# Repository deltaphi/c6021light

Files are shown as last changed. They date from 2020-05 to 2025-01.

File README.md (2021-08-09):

connect6021 light für Keyboard 6040
===================================



Project to connect one or several Keyboard 6040s to CAN. This project replaces the 6021 in your system.

To find out more about how to use the c6021light, take a look at the [User Manual](c6021light/doc/c6021light_UserManual.md).

## Safety Notes

When a button on the Keyboard is released, the Keyboard generates a "Power Off" command.
Unfortunately, the command does not directly translate to CAN. On CAN, commands are always sent
to the address of a specific accessory. The Keyboard 6040 however addresses 8 accessories at once.
There is a heuristic in the software to guess the address of the accessory to turn off. However,
this heuristic can be tricked and a power off command may not be sent to the correct address.

Please make sure to independently limit the Power On time of all accessories.

## Notes on Supply Power

The Keyboard operates on 8V. Note that its power draw is quite significant at about 120mA for a
single device.

The I2C bus operates at 5V.

# I2C Bus

## Hardware

Belegung der Buchse (Keyboard 6040 links)
```
SDA  SCL  STOP GO        INIT 8V   8V
 2b   4b   6b   8b  10b  12b  14b  16b
 2a   4a   6a   8a  10a  12a  14a  16a
GND  GND  GND  GND  GND  GND  GND  GND
```

Federleiste DIN 41612 32-pol B/2
z.B. ept 102-90065

http://dl1zax.selfhost.de/ATMega/PDF/6022.pdf

## I2C Bus Communication

Zitat von [Dr. König's Märklin-Digital-Page](http://www.drkoenig.de/digital/i2c.htm) (Text von Walter Fiedler):
```
Für die Übertragung von Weichenstellbefehlen genügen drei Byte als Schaltanforderung.
Es sind dies die Bytes für Empfänger (Zentrale), Keyboard-Nr. (0 bis 15) und das Datenbyte.
Das Datenbyte enthält die Angabe der Decoder-Ausgangsnummer (Bits 0 bis 3) und der Decoder- Teiladresse (Bits 4 und 5).
Mit Bit 0 wird die Schaltrichtung bestimmt (0=Rot, 1=Grün), mit Bit 3 wird der Schaltstrom eingeschaltet.
Da mit einem Keyboard (6040) vier Decoder angesprochen werden können, bestimmen die Bits 4 und 5, um welche Vierergruppe von Tastenpaaren und somit für welchen der vier für dieses Keyboard zuständigen Decoder sich der Schaltbefehl handelt.
Bei der Bildung der realen Decoder-Adresse (im binären Zahlenformat) stellen diese zwei Bits die Bits 0 und 1 dar. Die vier Bits der Keyboard-Adresse bilden dann die Bits 2 bis 5 der Decoder-Adresse. Diese Decoder-Adresse wird noch um 1 erhöht, da die Decoder-Adressierung im Märklin Digital-System immer mit der Adresse "01" beginnt. Somit können maximal 64 Decoder im Bereich von "01" bis "64" angesprochen werden.
Aufbau des Datenbytes:

    Bit 0 = Schaltrichtung, 0=Rot, 1=Grün
    Bit 1 = Decoderausgang LSB (Least Significant Bit)
    Bit 2 = Decoderausgang MSB (Most Significant Bit)
    Bit 3 = Schaltstrom, 0=aus, 1=ein
    Bit 4 = Decoder-Teiladresse LSB
    Bit 5 = Decoder-Teiladresse MSB 

Aufbau der Schaltanforderung:

Empfänger		Sender			Datenbyte		Stoppbits
1111 1110	0	001X XXX0	0	00XX XXXX	0	10
Zentrale	Q	Geräte-Adr.	Q			Q

Die Bestätigung von der Zentrale lautet:

Empfänger		Sender			Datenbyte		Stoppbit
001X XXX0	0	1111 1110	0	00XX XXXX	0	0
Geräte-Adr.	Q	Zentrale	Q			Q

```

Sequenz

Taste 0 rot

0xfe 0x20 0x08

0x20 0xfe 0x08 (Osci wA 0x10 -> Data 0x20)

### I2C Messages

Devices communicate over I2C. The system is multi-master, i.e., any device that has data to send
as as a master. Read from slave devices is not used.

The message format for Keyboards (Accessory commands) is as follows:

receiver sender data

* receiver is the I2C slave address the message is sent to. Thisi s not sent as a separate data
  byte but as the address byte of the I2C communication.
* sender is the I2C slave address under which the originator of the message can be reached.
* data The data byte, containing the action to be performed.

#### I2C Device Addresses

Note that I2C addresses are 7 Bit. However, the above mentioned fields are all 8 bit. In practice,
this results in the fact that the receiver address and sender address are shifted by 1 bit. In the
following, all addresses are given as their I2C slave address repesentation (i.e., the value
observed in the receiver field).

* The Central Unit uses the slave address 0x7F.
* Keyboard 0 uses a slave address of 0x10. The Keyboard address is derived from the DIP switches on
  the back.

#### I2C Data Byte

The data byte is constructed as follows:

`[0 0 Decoder_MSB Decoder_LSB Power Output_MSB Output_LSB Direction]`

Addressing on decoders on I2C is centered around the original approach, where a decoder had one
decoder address (set with DIP switches) and eight outputs. The KEyboard Address together with
the Decoder_* bits identify a decoder. The Output_* bits together with the Direction bit identify
one output of the decoder.

Modern Systems use individually addressable decoders (Keyboard Address + Decoder_* + Output_*) and
treat the direction separately.

### Keyboard Message flow

The Keyboard does not need any initialization. As soon as 8V are applied to one of the power pins
and the I2C lines are pulled up to 5V (a 10k resistor on each line does the job) it starts up and
the turnout indicators set at the last shutdown light up.
 
When a button is pressed, a message is sent to the Central Unit. When no Device with the address
of the Central Unit is present on the bus, the `receiver` byte will not be Acknowledged. In this
case, the Keyboard will abort transmission of the remaining bytes. It will then try resend the
message immediately and indefinitely, possibly blocking the bus.

If the message is received (i.e., a device with the address of the Central Unit is present on the
bus and ACKs the bytes), the Keyboard expects a response. If the response is not received, it
resends its original request indefinitely about once per second.

If no response is received, the indicators on the Keyboard don't change. Also, pressing additional
buttons has no effect. The Keyboard is stuck processing the original request. If a response is
received even when no corresponding request was sent, the indicators always change and no further
processing takes place on the Keyboard.

#### Power On/Off

When a button is pressed, a "Power ON" message is sent. When a button is released, a "Power OFF"
message is sent. However, due to the Decoder-Based addressing scheme, the "Power Off" message is
not addressed towards a specific turnout but towards the decoder Address, i.e., all 8 outputs are
considered to be unpowered.

# LocoNet

## Hardware

Looking from the top, the lines on the LocoNet connector are as follows:

```
 6      5    4    3     2   1
PWR    GND DATA  DATA  GND PWR
+8V    0V  +14V  +14V  0V  +8V    (Measured from IB1)
+9V    0V  +8,7V +8,7V 0V  +9V    (Measured with J31/J32 closed, 10V supply voltage)
+11,4V 0V  +10V  +10V  0V  +11,4V (Measured with J31/J32 closed, 12V supply voltage)
```

## Message Sequence for Dispatch

Recorded from IB1.

Request dispatch form FREDI, no Slot in dispatch:
```
LN RX:  ba 0 0 45 [OPC_MOVE_SLOTS] 0 -> 0
LN RX:  b4 3a 0 71 [OPC_LONG_ACK]
```

Dispatch engine 50 on IB1:
```
LN RX:  b5 1 10 5b [OPC_SLOT_STAT1] Slot: 1 Stat1: 0x10
LN RX:  bf 0 32 72 [OPC_LOCO_ADR] Addr 50
LN RX:  e7 e 1 10 32 0 0 7 0 0 0 10 4 26 [OPC_SL_RD_DATA] Slot: 1 Stat: 16 Addr: 50 Speed: 0 Dirf: 00 ...
LN RX:  ba 1 0 44 [OPC_MOVE_SLOTS] 1 -> 0
LN RX:  e7 e 1 20 32 0 0 7 0 0 0 10 4 16 [OPC_SL_RD_DATA] Slot: 1 Stat: 32 Addr: 50 Speed: 0 Dirf: 00 ...
```

Request dispatch from FREDI, Engine 50 in dispatch:
```
LN RX:  ba 0 0 45 [OPC_MOVE_SLOTS] 0 -> 0
LN RX:  e7 e 1 30 32 0 0 7 0 0 0 10 4 6 [OPC_SL_RD_DATA] Slot: 1 Stat: 48 Addr: 50 Speed: 0 Dirf: 00 ...
LN RX:  ef e 1 30 32 0 0 7 0 0 0 10 4 e [OPC_WR_SL_DATA] Slot: 1 Stat: 48 Addr: 50 Speed: 0 Dirf: 00 ...
LN RX:  b4 6f 7f 5b [OPC_LONG_ACK]
```

# Overall Communication Pattern

connect 6021 light connects the following bus systems:

* CAN
* I2C
* LocoNet
* XPressNet

In the future:
* MM2-Sniffer
* IR Receiver
* Serial Commands

There should be a central routing task that iterates over all ingress ports and if data is available, forwards the data over the respective egress ports.

Ingress and Egress may be polling-based (e.g., CAN) or interrupt-based (e.g., I2C, LocoNet). Also, input may be driven by concurrent tasks (Serial?).
Polling-based operation complicates scheduling, as the routing task can never go to sleep. It would be helpful if 

As for Datastructures: Is there an ingress queue/egress queue per bus, or is there a central queue that also notes down the ingress bus?

Overall Tasks:
* RoutingTask (needs: RR32Can, DataModel, HAL for CAN, HAL for I2C)
* Console Task

ISRs:

* I2C ISR (Send/Receive, Ingress/Egress Buffer. Egress can not be an OS queue.)
* LocoNet ISR (Send/Receive)

## Task/ISR Design

I2C ISR:
* TX Buffer, RX Buffer
* Bytes are read into RX Buffer. When buffer is full, place message into message queue (Copy!). Notify routing task when Message is complete (copy!). -> Note: As long as the RX part does not overrun, the Queue is not necessary. Code change may involve changing the synchronization primitives.
* Routing Task places TX message into queue (copy!). When TX Buffer is free, it copies (copy!) a message from the queue to the TX Buffer and starts the ISR. -> Note: As long as the TX part does not overrun, the Queue is not necessary. Code change is only adding the queue operation into the routing task.

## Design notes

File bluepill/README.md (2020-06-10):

STM32 C6021Light
================

Universal Maerklin CAN to Maerklin I2C / RS485 / Loconet Board

3D Board

Based on Blue Pill

STM32F103C8T6 microcontroller development board

using libopencm3 (real OpenSource - no questionable STMicroelectronics License)

CAN-Interface
-------------
```
/* CAN1 / CAN GPIO */
#define GPIO_CAN_PB_RX                  GPIO8           /* PB8 */
#define GPIO_CAN_PB_TX                  GPIO9           /* PB9 */
/* I2C2 / I2C GPIO */
#define GPIO_I2C2_SCL1                  GPIO6           /* PB6 */
#define GPIO_I2C2_SDA1                  GPIO7           /* PB7 */
```

Flashing Serial
---------------
using SWD interface with st-flash or serial loader stm32-flash (works only with USART1)

```
/* USART1 GPIO */
#define GPIO_USART1_TX                  GPIO9           /* PA9 */
#define GPIO_USART1_RX                  GPIO10          /* PA10 */
```

Compile under Ubuntu/Raspbian
-----------------------------
```
sudo apt-get install git gcc-arm-none-eabi stm32flash

sudo mkdir -p /embedded/arm-cortex/src
sudo chown -R "$(whoami).$(whoami)" /embedded

cd /embedded/arm-cortex/src
git clone https://github.com/libopencm3/libopencm3.git
cd libopencm3
make PREFIX=arm-none-eabi-

cd ~
git clone https://github.com/GBert/railroad
cd railroad/c6021light/bluepill
make # make stm32flash
```

Links
-----

more information here: https://wiki.kewl.org/dokuwiki/boards:vcc-gnd

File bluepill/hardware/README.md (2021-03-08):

Aenderungen
===========

```
1.0 Initiale Version

1.1 2020/06
    CAN RJ45 Pin 5 getrennt um CdB konform zu bleiben
    Buchse verschoben damit die gewinkelte Version besser passt
    DCDC Enable 12V getrennt
    Mehr Platz fuer DCDC Wandler
    USB/Seriell Wandler: 0 Ohm Widerstaende entfernt
    UART Leiste angepasst

1.2 2020/12
    Loconet C32 entfernt

1.3 2021/01
    TxD und RxD getauscht auf J52 Pin Header für Standard USB2Serial Module

1.4 2021/03
    mehr Platz für Spannungsregler
    C30 wahlweise 2,5 oder 5 mm Rastermaß
    
```

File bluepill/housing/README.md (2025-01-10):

The Housing was created using [OnShape](https://www.onshape.com/).
Find the original document at [c6021light Housing](https://cad.onshape.com/documents/e49e89ad6c23c5cdc841251d/w/302afb60d0e915079a89c67e/e/e77f569449b81789304b1466).

This folder currently contains an export of the Tag "V3".

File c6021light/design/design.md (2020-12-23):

# C6021 Light Software Design

The c6021light software consists of several building blocks and several OS tasks.

```plantuml
@startuml Software Overview

component RoutingTask

component ConsoleTask
component ConsoleManager

component DataModel

package "hal" {

component stm32usart
component stm32i2c
component stm32can
component stm32eepromEmulation

component libopencm3
}

package "Libraries" {
    component RR32CanLibrary
    component LocoNet
    component AtomicRingBuffer

    component FreeRTOS
    component microrl
    component nimaltd_ee
}

@enduml
```

## Tasks and Interrupts

The following FreeRTOS tasks exist in the system:

* RoutingTask
* ConsoleTask

ConsoleTask is a low-priority task, as it never blocks. RoutingTask is the highest-priority task in the system and is run only when there is data to be forwarded.

The following component make use of interrupts:

* stm32usart (DMA1 Channel4 Transmission Finished)
* stm32i2c (Transmission complete, I2C Error Handling)
* stm32can (CAN Message Received)
* LocoNet (TIM2 Timer Compare interrupt)

## Serial Command Line Interface and Output

c6021light makes use of the command line to print information data such as received and transmitted packages as well as to offer a command line interface to configure settings, such as the rail protocol to be used for turnout requests.

Implementation of this interface is spread over the following components:

* ConsoleTask
* ConsoleManager
* microrl
* stm32usart
* AtomicRingBuffer

stm32usart implements the serial communication to a remote device, e.g., a PC using a USB-to-Serial adapter. For the output path (c6021light to PC) stm32usart implements the `_write()` syscall. `_write()` copies the provided string data to a circular buffer (thereby using AtomicRingBuffer) and starts a DMA transfer to output the buffered data on the serial interface.

If the provided data fits into the buffer, the call returns after copying the data and starting the DMA. If the provided data does not fit into the buffer, `_write()` will busy-wait until all of the data could be forwarded into the buffer.

When the DMA transfer completes and there is data left in the buffer (e.g., because more data was added while a DMA transfer was ongoing), the DMA transfer is restarted with the new data.

For the input path (PC to c6021light), stm32usart provides the call `pollSerial()`. This call will return whether a character was read and if so, also return the appropriate character. `pollSerial()` is called by the ConsoleTask in an infinite loop, thereby polling for serial input. If data is read, ConsoleTask inputs the read data into microrl.

microrl provides command line parsing, command line history and command line completion. When a user enters a valid command, the command is mapped to a C function which is subsequently executed. ConsoleManager holds the configuration for microrl as well as the implementation of the applications.

## Runtime Configuration Data

c6021light allows runtime configurable settings to be done via the command line interface. The settings data is stored in the topmost program flash page. The following components interact with the configuration data:

* ConsoleManager
* DataModel
* stm32eepromEmulation
* FlashFairyPP

DataModel holds the actual runtime configuration data. All components wishing to read or write configuration data must do so by accessing a central instance of DataModel. ConsoleManager can be used to trigger a write of the current DataModel to persistent flash storage from the command line interface. Flash handling is performed by FlashFairyPP, where stm32eepromEmulation adds a few callbacks to map FlashFairyPP to libopencm3.

## Bus communciation routing

For every bus, there is a bus-specific communication implementation: stm32can, stm32i2c, LocoNet.

### stm32can

The stm32can part contains setup and reception/transmission of CAN messages. Messages are received through the CAN0 RX ISR. Whenever the interrupt is executed, all messages pending in the buffer are copied to a FreeRTOS queue and a task notification is sent to the RoutingTask.

```plantuml
@startuml stm32can message reception

CANCell -> stm32can: CAN RX ISR
stm32can -> canrxq: Copy message from HW FIFO to OS Queue
stm32can -> RoutingTask: Notify
canrxq --> RoutingTask: Get Message for Routing

@enduml
```

For transmission, messages are synchronously sent to the transmit mailbox of the CAN cell.

```plantuml
@startuml stm32can message transmission

RoutingTask -> stm32can: Send Message
stm32can -> CANCell: can_transmit()

@enduml
```

All interaction is based on RR32Can data types.

### LocoNet

The LocoNet library uses a level change interrupt and a timer compare interrupt to simulate a UART interface in software. It makes use of Hardware Timer TIM2.

To receive a LocoNet packet, the SW UART implementation of LocoNet recieves individual bytes which are then stored in a circular buffer. ConsoleTask is currently abused to poll wheter LocoNet has received new bytes and if so, to wakte the RoutingTask. However, ConsoleTask will wake RoutingTask even if only a partial message was received. To determine whether a complete message was received, RoutingTask asks the LocoNet library for the next message. The LocoNet library will provide a message only when a complete message is available in the buffer.

Note that in case a message wraps around in the buffer, the LocoNet library will briefly suspend interrupts to copy the message to a contiguous location in the circular buffer.

To send a LocoNet message, LocoNet sets up a message for transmission and then busy-waits until the timer interrupt has finished sending all bytes of the message. busy-waiting is necessary as the dat ais read from the caller-provided pointer, it is not copied to an internal buffer.

### I2C

When idle, the I2C hardware is configured as an I2C slave with address 0x7F. Other devices may send messages to this ID. Message bytes are received by the I2C1 ISR. A message is considered to be completely received when an I2C Stop Condition occurs or when an I2C Bus Error interrupt occurs. The latter enables successful interaction with certain non-conforming devices. When a message is successefully received, it is enqueued in the i2crx FreeRTOS queue and the RoutingTask is woken.

To send a mesasge via I2C, a caller needs to put the message into the i2ctx queue and then call `startTx()`. If a transmission or reception is already ongoing, `startTx()` will do nothing. The next transmission or reception is started automatically once the current action completes. If no interaction is currently ongoing, `startTx()` causes the Hardware to send an I2C Start Condition which triggers subsequent calls to the I2C ISR, which then, in turn, transmits the individual bytes of the message.

When the I2C bus is empty, apart from c6021light, every attempt at transmission will be met with an Acknowledgement Failure (AF). In case of an AF, the current message is discarded. The I2C interface is not sent into an error state but following messages are transmitted in the same way. If the bus remains empty, every message will be discarded with an acknowledgement failure. If a device "suddenly" appears on the bus that receives the message, communication will resume.

## RoutingTask

The operating principle of the routing task is that messages received from every bus are first converted into their representation as it would be on the CAN bus. Next, a routing decision is taken. Currently, the routing decision is to forward a message to every bus apart from the bus that it was received from. Finally, for every bus, the CAN representation is converted to the respective bus representation and a message is sent on the respective bus.

Note that for most busses, the respective library used offers capabilities to decode and handle or to send bus messages. However, for many cases these implementations are not used, as the resulting software design leads to a jumble of hard-to-follow callbacks and repeated implementation of routing decisions and forwardings. However, to enable operations other than forwarding, the c6021light considers itself to be a RR32Can::Station instance that is not directly connected to any bus. Instead, the RoutingTask forwards every received message to the RR32Can::Station for processing.

Currently, the only processing that occurs is to turn on the LED on PC13 if any bus signals a stop mode and to turn off the LED if any bus signals a start mode.

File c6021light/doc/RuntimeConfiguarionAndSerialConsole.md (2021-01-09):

# Runtime Configuration

Various settings of the c6021light can be adjusted at runtime using the serial interface. To connect to the serial interface of the c6021light, follow the instructions on the project Wiki for [Connecting to the serial console](https://github.com/deltaphi/c6021light/wiki/ConnectToSerialConsole). Make sure that you can see the command prompt `c6021light > ` before continuing.

## Interacting with the Serial Console

The c6021light has a built-in help that tells you about possible options available in your version of the software. To display the help, simply type `help` into the serial console and press Enter. On the current version of the software, the help looks as follows:

```
c6021light > help
Available commands:
  config ... - Change runtime configuration.
  flash ... - Operations on persistent storage.
  lnSlotServer ... - Control the LocoNet Refresh Slot server.
  canEngineDB ... - Control the Can Engine DB.
  help - Display this help message.
c6021light >
```

Each line consists of several elements. The first element is always a *command*, e.g., `config`. The command tells the c6021light what you want to do. The second element are three dots `...`. These dots indicate that a command cannot be executed on its own but has further subcommands. Note that the dots are optional. For example, `help` does not have subcommands. If there is a help text configured for a command, the dots are followed by a dash (`-`) and the actual help text.

To find out more about available subcommands, simply type the name of the command and press Enter. If the command is incomplete, you will automatically get another help text for the next level of subcommands. Consider the following example:

```
c6021light > config get
Available commands:
  config get ... - Display configuration value.
  config set ... - Modify configuraiton value. 
c6021light >
```

You can use this to explore the tree of commands offered by the c6021light. Let's take the example a bit further and look at `config set turnoutProtocol`:

```
Available commands:
  config set turnoutProtocol MM2
  config set turnoutProtocol DCC
  config set turnoutProtocol SX1
```

Neither of these commands have dots. That means that these are complete commands. If you were to type them in, they will immediately be executed.

Note that when you use the serial console to change a configuration value, the change takes effect immediately. However, the change will be forgotten by the next reset (e.g., power cycle of your layout) unless you [persist the configuration](#persistent-storage-of-configuration-options).

# Serial Configuration Options

This is an incomplete description of runtime configuation options. Refer to the command line help of your c6021light to find out what options your firmware version of the c6021light offers.

| Setting | Possible Values | Default Value | Description |
|---|---|---|---|
| `turnoutProtocol` | `MM2`, `DCC`, `SX1` | `MM2` | Protocol to address turnouts on the Rail. Only affects forwarding of messages on CAN. |
| `lnSlotServer` | `disabled`, `passive`, `active` | `disabled` | Forwarding of Locomotive control commands between CAN and LocoNet. Disabled completely disables forwarding of Locomotive control messages. Passive requires a LocoNet Central on LocoNet. Active (not implemented) simulates a LocoNet Central for other control terminals on LocoNet. |

# Convenience Features of the Serial Console

The serial console of the c6021light offers two convenience features: Tab-completion and command history.

## Tab Completion

When you enter a prefix command of a command known to the c6021light, press the `Tab` key to trigger the tab completion. If the prefix you entered matches exactly one command, the c6021light will auto-complete the remainder of the current command word for you. For example: ```c6021light > h<Tab>``` will complete to ```c6021light > help```. In contrast, ```c6021light > c<Tab>``` will not auto-complete, as the 'c' could match either `config` or `canEngineDB`. If you extend the command line to ```c6021light > co<Tab>```, the command will complete to ```c6021light > config```.

## Command History

If you want to execute a previous command again or want to edit a previous command, you can use arrow up and arrow down to navigate through the command history.

Note that this feature does not work with all serial terminal applicaitons. Specifically, it is known not to work with the PlatformIO IDE serial terminal.

# Persistent storage of configuration options

When you change a value using the serial console, the change takes effect immediately but is not persistet across resets of the c6021light such as caused by a power cycle. To store configuration data across resets of the boards, the c6021light utilizes the internal flash of the STM32 controller on the bluepill board.

The serial interface offers several commands to interact with the flash memory. Use `flash save` to save the current configuration persistently. The configuration will automatically be loaded every time the board is reset.

To revert the c6021light to the default settigns of the software version currently installed, use the command `flash format`. It is not usually necessary to use this command.

If you feel really curious, `flash dump` gives you a raw view into the contents of the flash pages used to store configuration data. This command is used during software development.

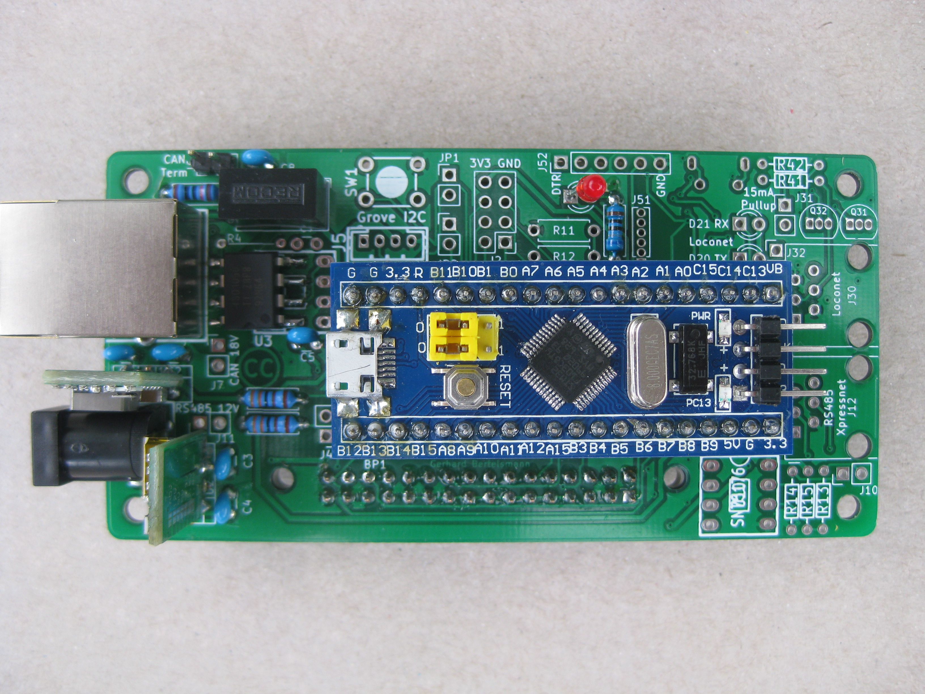
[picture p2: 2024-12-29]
pictures/board_02.jpg

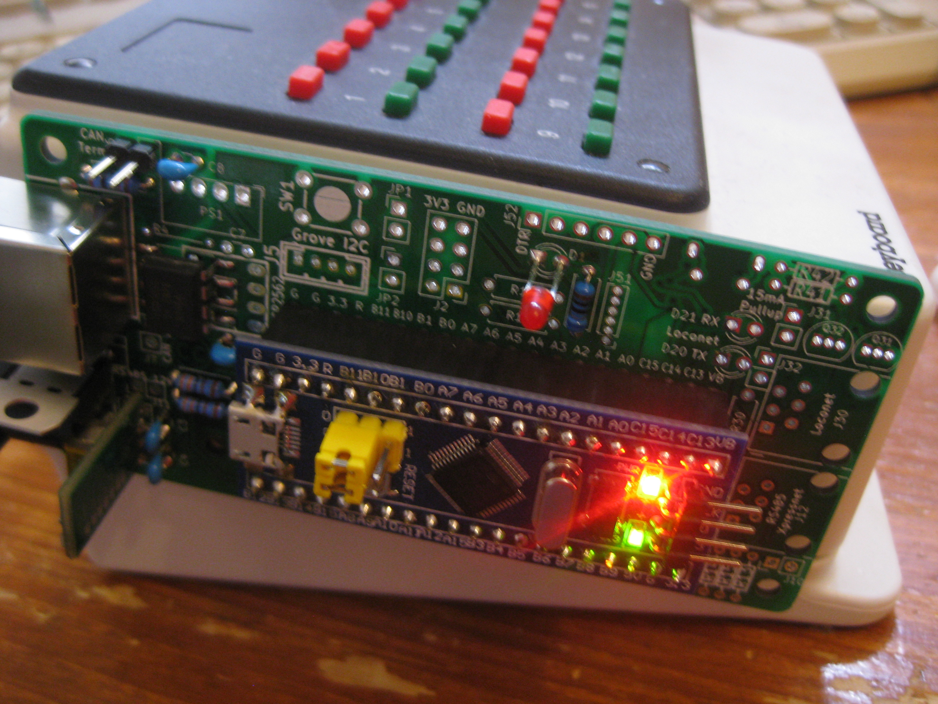
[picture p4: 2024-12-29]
pictures/board_kb_01.jpg

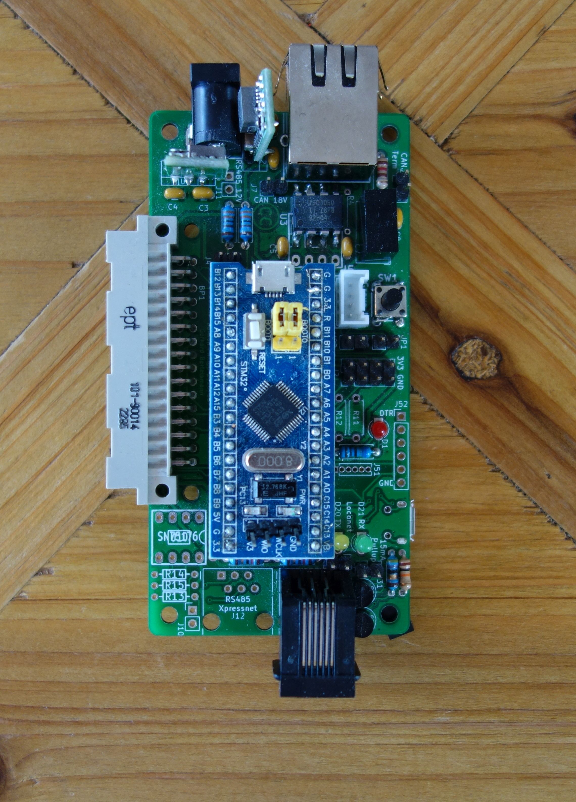
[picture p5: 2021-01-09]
c6021light/doc/images/c6021light_pcb_v1_0.jpg

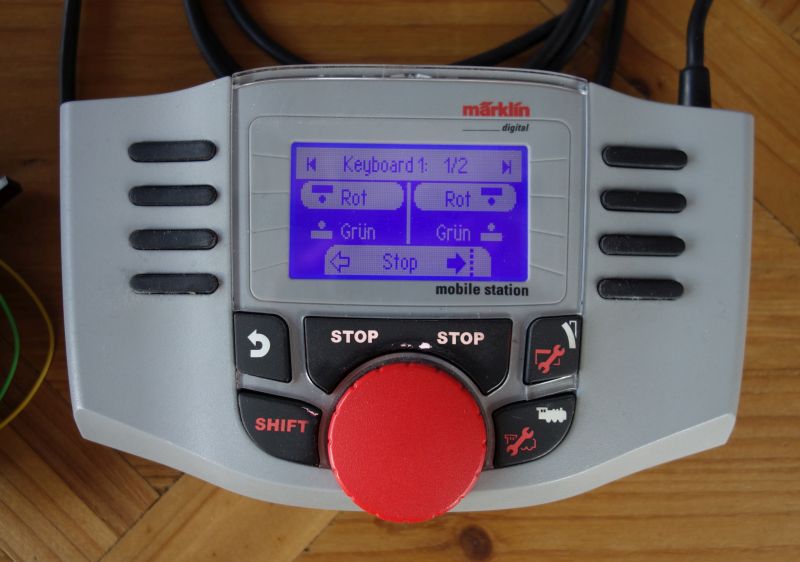
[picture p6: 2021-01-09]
c6021light/doc/images/ms2_turnout_stop.jpg

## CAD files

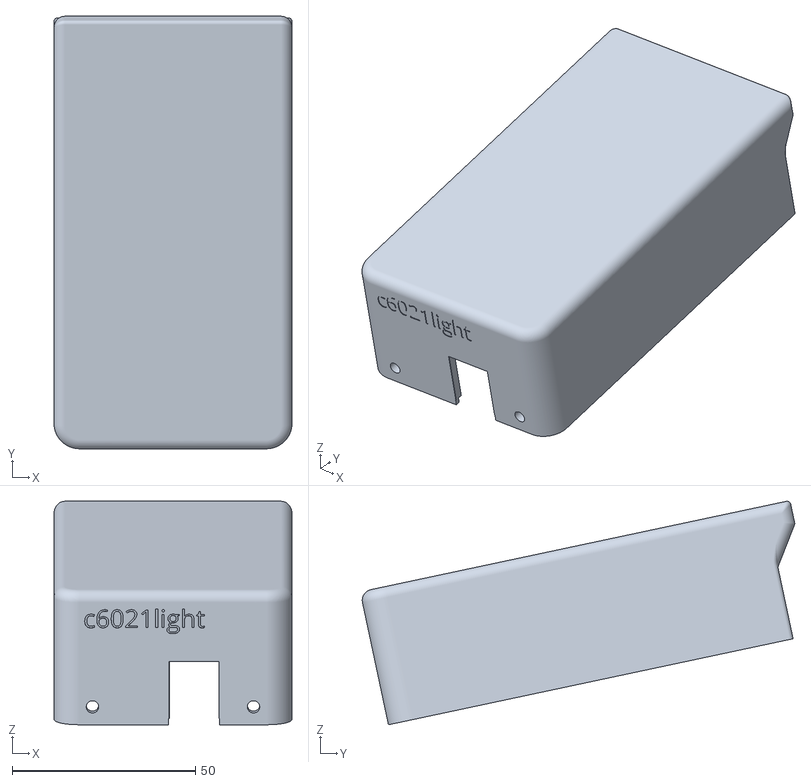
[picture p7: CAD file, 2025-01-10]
bluepill/housing/c6021lightHousing - Top.stl
65.0 x 118.1 x 61.1

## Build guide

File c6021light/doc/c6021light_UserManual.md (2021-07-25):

# c6021light User Manual

c6021light is a project that connects devices on the following Model Railroad control networks:

* Marklin devices on CAN bus
* Marklin devices on I2C bus
* LocoNet devices

In the current version, c6021light transfers turnout commands between all three busses.
It also transfers sensor commands (e.g., from an S88 Bus or LocoNet track sensor), synchronizes the Stop/Go state (Track Power On/Off) and translated Locomotive control commands between Marklin System CAN and LocoNet.

Unfortunately, transfering locomotive control commands is not as straight-forward as transfering other commands. c6021light employs heuristics in an attempt to provide a seamless railroading experience. Nevertheless, it is in the nature of these heuristics that they may fail and that you may have to manually configure c6021light to correctly transfer locomotive control commands. See the [General Operation](GeneralOperation.md) section for more details.

*Please be aware of the following safety note: When controlling accessories such as turnouts from the Marklin Digital devices on an I2C bus, there is no reliable way to translate a "Turnout Power Off" event to other bus systems. c6021light employs a heuristic to guess which accessory output should be powered off. However, a power off command still may not be sent to the correct accessory, possibly causing permanent damage to your model railroad, e.g., by burning out a turnout actuator coil, possibly even setting the accessory on fire. Make sure to use additional, independent protective measures to limit the on-time of sensitive devices attached as an accessory to avoid any potential for damage.*

## Table of Contents

The user manual for the c6021light is split into several chapters.

**As a new user, you should begin setting up your c6021light with the [Getting Started Guide](GettingStarted.md).**

* [Getting Started Guide](GettingStarted.md) - This is the entry point for all new users. Even if you already have your c6021light running, it is recommended to at least skim this chapter as it will also introduce you to some gneral concepts of the c6021light.
* [General Operation](GeneralOperation.md) - Details the features of the c6021light as well as its operation principles.
* [Runtime Configuration & use of the Serial Console](RuntimeConfiguarionAndSerialConsole.md) - Details how to access the serial console and how to edit and persist the configuration.

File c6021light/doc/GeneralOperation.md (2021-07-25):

# General Operation

## LED Status Indicators

The c6021light features two status indicator LEDs: The "On-board LED" and the "Extra LED".

### On-board LED

The On-board LED can convey two types of information: Whether the system is in a regular operation state (LED on), whether a [CAN Engine Database Download](#can-engine-database) is ongoing (LED blinks slowly), or whether the system is in an error state (LED blinks fast).
There is also a mode where the LED is off, which is currently unused.

### Extra LED

Functionality of the "Extra LED" is described in the section on [System Power Status Indication](#system-power-status-indication).

## Turnout Control

Turnout contol messages are automatically forwarded between all bus systems. 

Turnout control messages on CAN carry information about the rail protocol used to contact the turnout decoder, whereas messages on I2C and LocoNet do not carry this information. Therefore, the configuration value `turnoutProtocol` is used to add protocol information to turnout control messages when forwarding to CAN. Similarly, the protocol information is stripped from messages when forwarding from CAN to other bus systems.

Devices on the I2C bus send out turnout control request messages and expect turnout control response messages in return, before they update their state indication (Keyboard) or proceed with processing (Memory). In the current version of the software, turnout control response message are generated only by a central device on the CAN bus that is not in the "STOP" mode. Devices on LocoNet do not generate turnout control response messages.

## Sensor Messages

Sensor messages are forwarded as-is between CAN and LocoNet in both directions. No configuration is required or possible.

## System Power Status (Stop/Go)

Stop and Go messages are forwarded as-is between CAN and LocoNet in both directions. No configuration is required or possible.

In addition, c6021light provides an indication of the last observed system state using the "Extra LED".

### System Power Status Indication

The "Extra LED" indicates whether the c6021light considers the system to be in a "Stop" state (LED off) or a "Go" state (LED on). In addition, the c6021light will flash the "Extra LED" when it has no information about the current Stop/Go state of the system.

The c6021light considers Stop/Go commands from all bus systems equally. Whenever a STOP- or GO-Command is received, it updates its internal state accordingly and sets the state of the LED. Not that the Stop/Go state of the system may be out of sync if any component of the system is reset or disconnected.

### System Power Status Download

After power on or reset, the c6021light has no information about the Stop/Go-State of the system and will start to flash the Extra LED. In parallel, it will send request messages to determine the Stop/Go state on the CAN bus. Unfortunately, not all CAN-based railroad control systems respond to this message. In this case, the c6021light cannot determine the Stop/Go state of the system until the first STOP or GO command is observed on any bus.

Lack of the current system state does not influence the forwarding of STOP/GO commands between bus systems.

## Locomotive Control

*Note that Locomotive Control is an experimental feature that is currently under development. It is not fully available between all bus systems and in all directions. Even if it is available, it may spuriously fail.*

### Overview over Locomotive Control

In contrast to all other types of information forwarded by c6021light, Locomotive Control is a more complex task. Turnout control, track sensors and Stop/Go messages work similarly on all bus systems. Therefore, messages can be forwarded by simply translating message formats between the bus systems. 

Locomotive Control, however, useses widely different message types and even message interactions and addressing schemes across the different bus networks. c6021light is capable of translating the message interactions for Locomotive Control between LocoNet and Marklin CAN, provided that it has state information about the engine control happening on both bus systems.

On LocoNet, Locomotives are assigned a control slot by the LocoNet Master. The Slot is associated with a Locomotive Address (e.g., the DCC decoder address sent on the track), but all control messages contain only the slot number.

On CAN, Locomotives are assigned a unique ID (UID). The UID is associated with the Locomotive Address and the track protocol for the Locomotive Address, but all control messages contain only the UID.

To successfully forward Locomotive Control Commands between CAN and LocoNet, c6021light therefore must know the CAN Engine Database as well as the LocoNet Slot Database.

Note that CAN considers both the Locomotive Address as well as the track protocol used for the respective address, whereas LocoNet uses only the Locomotive Address. It is (at least in theory) possible to control several Locomotives that use the same address on different Protocols (e.g., one Locomotive using MM2-50 and another using DCC-50) from CAN. LocoNet would not be able to distinguish control commands for these engines. It is therefore recommended that you give unique Locomotive Addresses to all of your Locomotives, independent of the rail protocol they use.

### Locomotive Control using c6021light

Forwarding of Locomotive control message is only enabled, when the configuration setting `lnSlotServer` is not set to `disabled`.
Furthermore, a CAN Engine DB must be available for the c6021light to be able to forward incoming Locomotive Control Messages.

#### LocoNet Slot Server

The LocoNet Slot Server offers two operating modes: `passive` mode and `active` mode.

In `passive` mode, the c6021light expects a LocoNet Master to be present on the bus, e.g., an Uhlenbrock IntelliBox. The LocoNet Master controls the assignment of Engines to Slots. In `passive` mode, the c6021light monitors the LocoNet bus for ongoing slot assignments and Locomotive Control Commands and caches all received information in its internal Slot Server.

In `active` mode, the c6021light acts as a LocoNet Master itself. Thus, it controls the assignment of Locomotives to slots both as other devices on LocoNet request Locomotive control slots and as control messages from CAN are forwarded for Locomotives currently not assigned a slot.

In the current implementation, engine speed, direction and Functions F0-F31 are forwarded from LocoNet to CAN. If no additional measures are taken, c6021light produces messages to an engine using the address entered on the control device on LocoNet, using the MM2 protocol.

#### CAN Engine Database

The c6021light can also obtain the list of known engines from a central device on the CAN bus using the command `canEngineDB downloadEngines`.
An ongoing download is indicated by flashing the "On-board LED".

Note that the download time is proportional to the number of engines in your database.
It will typically take several seconds to complete.
You can at any time view the list of engines known to the c6021light using the command `canEngineDB dump` on the serial command line.

To avoid having to manually download the CAN Engine Database every time the c6021light is reset or powered down, the c6021light will try to download the CAN Engine Database after power-up. Over the first ten seconds of its operation, it will request a download of the CAN Engine Database once every second.

#### Forwarding between CAN and LocoNet

If an Engine Database is available on the c6021light, it will try to find an engine with an address that matches the address entered on the LocoNet-side. If a match is found, the c6021light will forward messages for that engine.

In the reverse direction, i.e., CAN to LocoNet, no information is transmitted unless an engine database is available. If an engine database is available, the c6021light will attempt to control engines on the LocoNet side when a control message is received on the CAN side. Control is currently limited to setting the engine speed. Engine direction or functions are not currently supported.

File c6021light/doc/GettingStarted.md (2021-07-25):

# Getting Started with the c6021light

So you have just soldered up your c6021light and now want to connect it to your model railroad layout. In this getting started guide we will show you how to start using your c6021light with a simple example setup.

## Prerequisites

To follow this guide, you will need the following:

* A c6021light loaded with firmware. If you need to update or install the firmware on your c6021light, please follow the [Instructions for Build & Upload](https://github.com/deltaphi/c6021light/wiki/Build-&-Upload) from the project Wiki. Continue reading here once you have the firmware installed on your c6021light.
* Power Supply for the c6021light. ([Example](images/c6021light_with_PSU.jpg))
* A Märklin Mobile Station 2 and Märklin Gleisbox. ([Example](images/ms2_gleisbox_srseii.jpg)))
* An RJ45 CAN breakoutport built into the Märklin Gleisbox or an Adapter cable to connect the Märklin Gleisbox to the RJ45 CAN port on the c6021light.
* A Märklin 6040 Keyboard. ([Example](images/Keyboard6040.jpg))

In our example setup, we will use a Märklin Gleisbox that has been modded with a [SRSEII](http://lnxpps.de/can2udp/srseII/) to get access to the CAN bus and a c6021light with the optional on-board USB-to-serial converter. For the purpose of the example, we run with no railway layout connected to the Gleisbox. However, we assume that turnouts on the railway layout are controlled using the MM2 protocol. Finally, we assume that the Märklin Keyboard is configured to address 0 (all DIP switches on the back set to the "Off" position). See an overview of our example system:

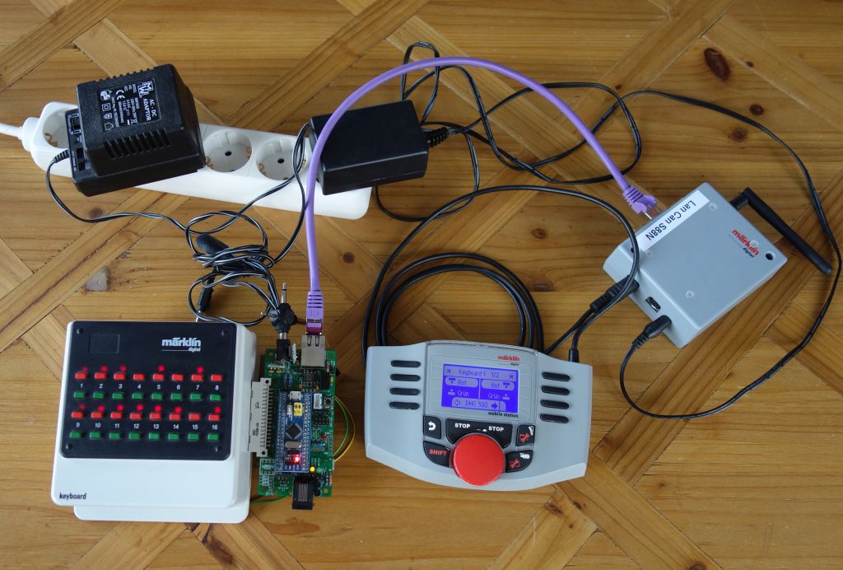
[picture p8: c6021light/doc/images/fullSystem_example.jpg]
Overview of the example system


## First look at the c6021light

The PCB of the c6021light looks roughly as shown in the image below. Depending on your specific setup and PCB revision, the details may be slightly different. Let's take a closer look at what we are seeing here.

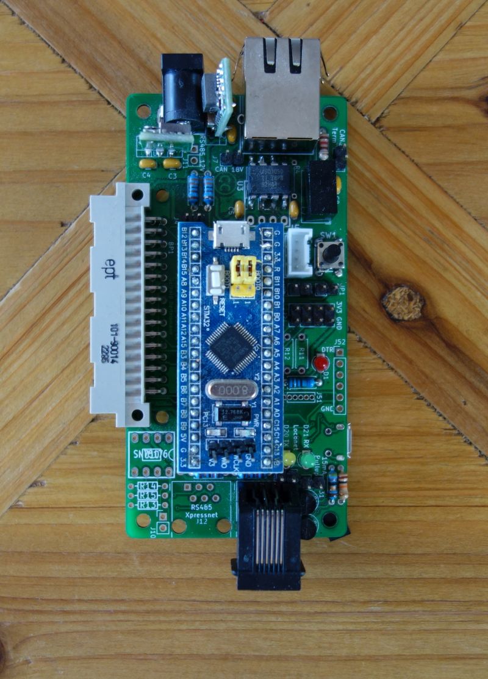
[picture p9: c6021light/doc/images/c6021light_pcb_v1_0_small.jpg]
Overview of the c6021light


At the center of the board, we can first see the BluePill board containing an STM32 Microprocessor - the heart and brain of the c6021light. On and around the PCB, we can see a bunch of connectors, LEDs and a button. We will first take a look at the connectors and then examine the LEDs and Button.
All elements described in the following are labelled in this picture:

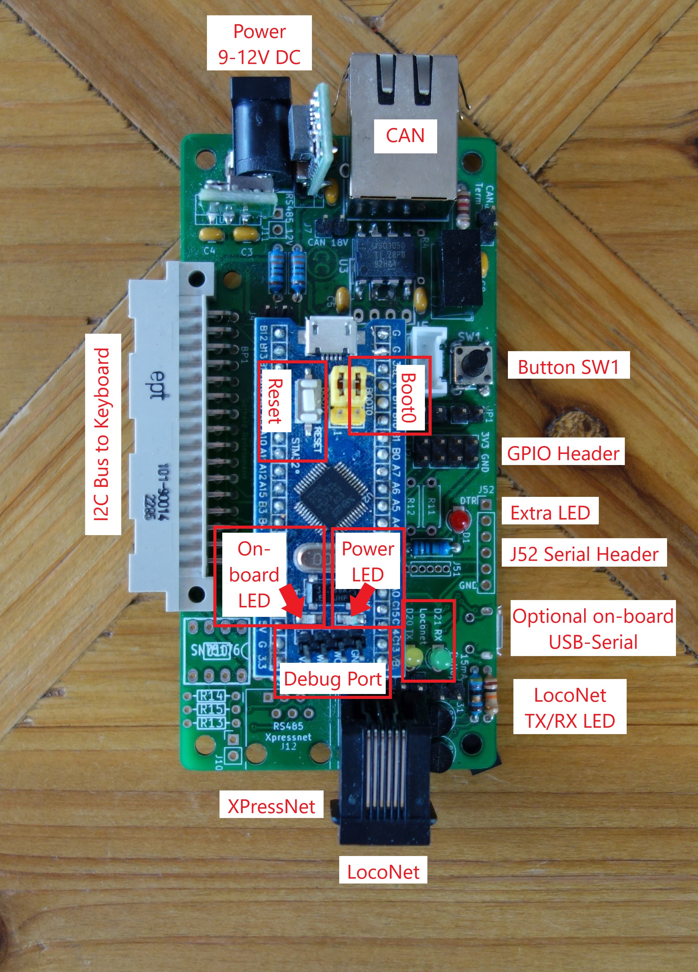
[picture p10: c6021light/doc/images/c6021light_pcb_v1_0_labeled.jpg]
Overview of the c6021light


### Connectors

At the top of the board, we see a barrel jack and an RJ45 port. The Barrel Jack is for power supply to the board, the I2C bus (i.e., the Märklin Keyboard in our example) and optionally other busses as well. The input voltage depends on the on-board voltage regulators used. It is recommended to use a 9V or 12V power supply.

The RJ45 port is the connector to the CAN bus. Its pin layout follows the Can Digital Bahn Project. You can download the pin layout from the [Can Digital Bahn Download Area](http://can-digital-bahn.com/infusions/pro_download_panel/download.php?did=35).

Moving around the board counter-clockwise, we next encounter the connector to the I2C bus, i.e., the Märklin Keyboard in our example. It is possible to mount straight or angled, male or female connectors. Your PCB may look different, depending on the connector you chose. In thie example, the c6021light is fitted with an angled male connector. Thus, it can be connected on the right hand side of the Märklin Keyboard.

On the bottom of the PCB, we find two more RJ11 connectors. The connector on the left (not populated in the image) connects to an XpressNet bus. The connector on the right offers a connection to a LocoNet network.

On the right hand side of the PCB, there are three more connectors. Bottommost is an optional Micro USB port, used for the optional on-board USB-to-Serial adapter (located on the back side of the PCB). Directly above the Micro USB port there is the Pin Header J52. J52 gives access to the same serial port as the on-board USB-to-Serial adapter. If you have not yet populated the on-board USB-to-Serial adapter, it is recommended to use an easily available USB-to-serial adapter board on J52 instead.

*Note [Issue #7](https://github.com/deltaphi/c6021light/issues/7): On some versions of the c6021light PCB, the RX and TX lines on J52 are swapped. If your PCB is affected by this bug, use jumper cables to connect the USB-to-serial adapter to the c6021light and cross over RX and TX in the process.*

Above J52, there is another 2x4 pin header. This pin header provides access to six GPIO pins of the processor as well as a 3.3V power supply and a Ground pin. It is intended for future expansion projects. If you plan an expansion project, please note that the 3.3V supply is fed from the on-board power regulator of the BluePill board. This regulator is not very powerful - i.e., you cannot draw a lot of current from this pin header.

Moving from the rim of the PCB to the center, there are two more noteworthy ports. At the bottom of the BluePill board, there is a small Pin header. This is the debugger port (e.g., ST-Link V2). Typical users do not need to use a debugger. However, having a debugger does come in handy for software development and to find more complex software issues.

At the top of the BluePill board, there is another Micro-USB port. This port is disabled and cannot be used on the c6021light. Do not connect anything to this port.

### On-Board Interfaces

The c6021light and the BluePill board feature a number of LEDs for information output as well as buttons and jumpers for configuration. 
We begin by looking at the LEDs and then move on to the buttons and jumpers.

#### LEDs

Starting at the bottom of the BluePill board, we first see two LEDs right above the debugger port.
The red LED on the right indicates whether the BluePill board is powered (LED lights up).
The yellow LED on the left gives status information on the system, e.g., whether a CAN Engine Database download is ongoing (Blinks slowly) or whether an error occured (blinks quickly).

Off to the right, next to J52, there is another red LED.
This LED indicates the Stop/Go state of the system (i.e., whether track power is off or on), if that information is known to the c6021light.

Below the red LED, next to the LocoNet port, there are two more LEDs. These LEDs indicate message transmission (LED to the right) and message reception (led to the left) on the LocoNet port.

#### Jumpers and Buttons

We again start by examining the BluePill board. At the top left of the board, we see a white button. This is the RESET button. To the right of the RESET button, we see two yellow jumpers labeled "Boot1" (left) and "Boot0" (right). Boot1 is currently unused. Boot0 is important when using a USB-to-serial connection to upload the firmware to the c6021light. More details on Boot0 are available in the [Instructions for Build & Upload](https://github.com/deltaphi/c6021light/wiki/Build-&-Upload) on the project Wiki.

Last, there is one more button off to the top right of the c6021light. This button is currently unused.

## Connecting the c6021light

To start using the c6021light in our example, start by plugging the c6021light into the Märklin Keyboard. Second, use an RJ45 network cable (straight cable, not a crossover cable!) to connect the c6021light to the CAN port of the Gleisbox. Next, connect the USB-to-serial adapter to the c6021light and to your PC. 

To power up the system, apply power to the Gleisbox and plug in the power supply for the c6021light.

* Note that in the current software version, the order in which you power up the devices does not matter. However, later software versions may make assumptions about whether other devices have already been powered up. We recommend to plug the Gleisbox and the c6021light into a common switchable power strip and thereby switch both devices on and off at the same time.*

The powered-up system should look roughly as follows:
Overview of the example system

Ensure that the Display of the Mobile Station 2 lights up and the Mobile Station 2 goes to its regular operating state, that the Power LED on the BluePill board turns on and that at least one LED on the Keyboard lights up.

### Troubleshooting

If the Power LED on the c6021light does not light up, ensure that the power supply for the c6021light is firmly connected to the board and that it is plugged into a live power outlet.

If no LED lights up on the Keyboard, make sure that the Keyboard is connected to the c6021light. Note that the connectors between Keyboard and c6021light do not excert substantial holding force. They can be connected and disconnected with little effort. For a good connection, the housing of the connector on the c6021light should brush against the housing of the Keyboard.

If the display of the Mobile Station 2 does not light up, ensure that the Gleisbox is powered. If the Gleisbox is powered, there may be an electrical problem on the CAN bus. Verify whether the Mobile Station 2 works when you have the Gleisbox connected only to power and to the Mobile Station 2.

If the display of the Mobile Station 2 lights up but the Mobile Station 2 does not enter its regular operating state, there is likely an error on the CAN bus. Try disconnecting the c6021light from the Mobile Station 2 and power-cycle the Gleisbox.

## First operation

A freshly installed c6021light runs at its default settings.
This means that it will transfer turout control commands, S88 sensor reports and the Stop/Go state between all attached busses.
Turnout Control commands on the CAN bus are sent to turnout decoders using the MM2 protocol by default.
Locomotive Control is disabled.

If your turnout decoders are using the MM2 protocol, you are now ready to test out the c6021light. Start by ensuring that system is in the "Go" state (track power is on, even if no track is connected). To this end, verify that the display of the Mobile Station 2 does *not* say "STOP". If it does, press the "STOP" button to put the system in the "Go" state. For reference, see images of the Mobile Station 2 on the default locomotive control screen in the [Stop mode](images/ms2_loco_stop.jpg) and the [Go mode](images/ms2_loco_go.jpg), as well as on the turnout control screen in the [Stop mode](images/ms2_turnout_stop.jpg) and the [Go mode](images/ms2_turnout_go.jpg). Next, bring up the turnout screen on the Mobile Station 2 by pressing the turnout button. You should see two turnouts presented in the screen. The label at the top indicates that you are seeing turnouts 1 and 2.

Now start switching Turnouts 1 and 2 back and forth on the Keyboard. You should now see the screen on the Mobile Station 2 reflect your turnout changes. If you happen to have a railroad layout connected to your Gleisbox, turnouts 1 and 2 will be switching.

Next, start switching Turnouts 1 and 2 back and forth on the Mobile Station 2. You should now see the indicator LED on the Keyboard reflect your turnout changes. If you happen to have a railroad layout connected to your Gleisbox, turnouts 1 and 2 will be switching.

 For reference, see the two following images showing an identical system, save for turnout 2 being switched to green in the second picture:

 Example System, Turnout 2 red
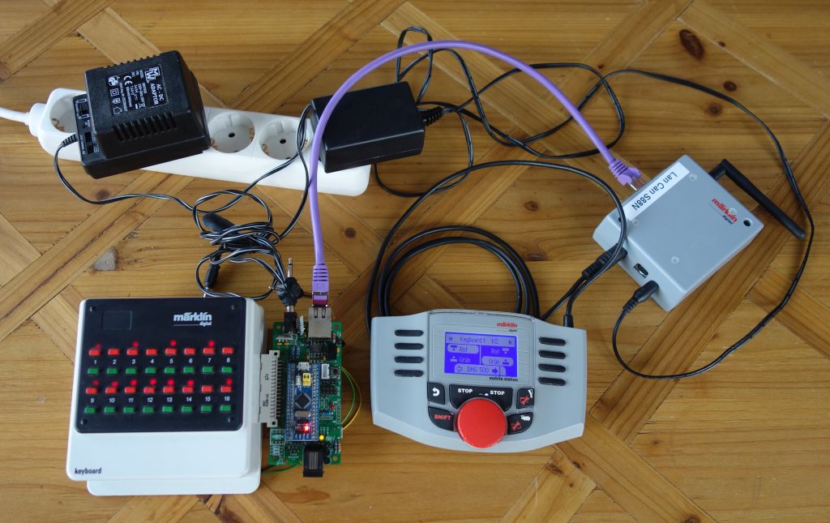
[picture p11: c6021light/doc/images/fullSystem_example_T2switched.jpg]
Example System, Turnout 2 green
 

If everything worked: Congratulations, you are now ready to use the c6021light!

### Troubleshooting

If turnout indicators do not change when you toggle the turnouts on either device, check whether the System is in the "Go" state. In the "Stop" state, the Gleisbox receives the turnout requests but does not generate response messages. Thus, indicators will not update.

If you control turnouts from the Mobile Station 2 and see the indicators update only on the Mobile Station 2, verify that the calbe for the CAN connection is firmly connected to the Gleisbox and the c6021light and that you are not using a crossover cable.

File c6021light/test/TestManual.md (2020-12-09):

# c6021light Test Manual

## Test CAN/I2C Interaction

Setup: Connect MS2 via CAN and Keyboard via I2C.

Test Steps:

1. Power up the System.
2. Test 1: Do the last Turnout settings on the Keyboard come up? Test is passed if the lights come up.
3. Bring up the Turnout screen on the MS2.
4. Put the MS2 in GO mode.
5. Switch Turnout 1 on the Keyboard Red-Green-Red-Green-Red.
6. Test 2: Does the light change on the Keyboard? Test is passed if the light changes according to each button press.
7. Test 3: Does the indicator on the MS2 change? Test is passed if the indicator changes according to each button press.
8. Repeat Steps 5.-7. for Turnouts 2, 4, 5, 15, 16 on the Keyboard.
9. Test 4 & 5: Repeat Steps 5.-7. but control the turnout from the MS2. Test for Turnouts 1, 2, 4, 5.

10. Set Turnouts 1-4 to Red on the Keyboard. The indicator lights must light up.
11. Test 6: Turn Turnout 1 to Green on the Keyboard. The test is passed if exactly the indicator light for Turnout 1 changes.

12. Switch at least one Turnout to Red. The indicator light on the Keyboard must light up.
13. Put the MS2 in STOP mode.
14. Test 7: Attempt to switch a RED turnout to GREEN and a GREEN turnout to RED from the Keyboard. Test is passed if the indicator on the Keyboard and in the MS2 do not change.
15. Test 8: Attempt to switch a RED turnout to GREEN and a GREEN turnout to RED from the MS2. Test is passed if the indicator on the Keyboard and in the MS2 do not change.

Perform the Test steps with the following busses connected:

* CAN, I2C, LocoNet
* CAN, I2C
* CAN, LocoNet
* CAN

The system is known not to work properly when CAN is not connected.

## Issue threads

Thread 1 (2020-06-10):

Support STOP Mode on I2C

deltaphi, 2020-06-10:
On I2C, responses are different between "STOP" mode and "GO" mode. Currently, c6021light behaves as if there was a perpetual "GO" mode.

Recommended behavior:
* On Request from I2C, c6021 stores the request and forwards the request on CAN.
* When a confirmation is received from CAN, the confirmation is forwarded to I2C. If the confirmation matches the stored request, the stored request is deleted.
* When a request is stored and no confirmation is received for 1ms, send a "STOP"-style response to the 6040.

deltaphi, 2020-06-13:
It turns out that the 6040 does not actually care about the "STOP"-Mode messages. Sending a response if and only if a response was received on CAN yields the resired behavior.

Closed 2020-06-13.

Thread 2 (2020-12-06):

C32 breaks LocoNet library

deltaphi, 2020-12-06:
The presence of C32 in the schematic converts the LnTx level to a peak, thus breaking LocoNet bus control for the STM32. In current vrsions, C32 must not be populated. In future versions, C32 should be removed.

GBert, 2020-12-09:
will be fixed in the new revision of the PCB

GBert, 2020-12-16:
C32 removed in PCB version 1.2

Closed 2020-12-16.

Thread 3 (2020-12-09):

I2C Hotplug does not work

deltaphi, 2020-12-09:
Expected behavior:
* No device connected to I2C, operation happens on other busses.
* Device is connected to I2C
* Device starts operating normally.

Actual behavior:
Device appears not to communicate after being connected (no reaction to actions on other busses, no messages forwarded to other busses).

Likely explanation is that the I2C ISR gets stuck in an error state, blocking further communication.

deltaphi, 2020-12-11:
Note that analysis of this may be hampered by the I2C RX Watchdog.

deltaphi, 2020-12-12:
Repoen, since the fix doesn't actually fix.

Closed 2020-12-12.

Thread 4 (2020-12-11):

I2C Message loss

deltaphi, 2020-12-11:
Under moderately heavy load, e.g., pressing turnout buttons 1-8 at only a few 100 ms intervals, some I2C messages appear to go missing.

Observation: After switching the second or third turnout, a Keyboard does not respond immediately to further button presses. IT usually takes about one second for a button press to be processed, before another button can be pressed.

Suspected reasons:
* STM32 loses I2C messages on RX.
* STM32 is delayed sending response messages.

Might have to do with LocoNet integration?

deltaphi, 2020-12-12:
With f78e5c32e this appears to be more of an off-by-some error. Possibly responses being held up in the queue? There is no back-to-back-transmission mode, yet.

Closed 2020-12-12.

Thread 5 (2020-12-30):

i2c without CAN

CuriousTimo, 2020-12-30:
Hi,

Love the work you are doing on this. I've ordered a blue pill to have a look at this and I did not connect anything but one 6040 keyboard. Somehow after the first press on the 6040 it gets stuck and keeps sending the last i2c message with a one-second interval. Reading Dr. Köning's site I guess that it is waiting for the acknowledgment.

```
2C RX: [0x7f 0x20 0x8] - Keyboard: 0, Decoder: 0, (Turnout: 0, Direction: RED  , Power: ON )
Accessory Switch. Details: Turnout:     0x3800, Human Value: 14337, Position: 0 (off, round, red) Power: 1 (on, button press)
```

Can you confirm that the i2c acknowledgment is only sent when there is a CAN device responding?
Or am I missing something here?

```
My Connections are:
- Blue Pill GPIO6 (PB6) <-> 6040 2b
- Blue Pill GPIO7 (PB7) <-> 6040 4b
- 8V                         <-> 6040 16b
- GND                      <-> 6040 GND

Blue Pill get 5V from FDTI and all GNDs are tied together.
```

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

deltaphi, 2020-12-30:
Hi CuriousTimo,

yes, the Keyboard does wait for an Acknowledgement to be sent and the c6021light does not generate an acknowledgement by itself. Currently, I found that acknowledgements are only available on the CAN bus, typically sent by a Gleisbox. Therefore, Acknowledgements are only forwarded, not generated by the c6021light itself. The benefit of this: The Gleisbox does *not* generate Acknowledgements when the system is in stop mode - as it can't switch turnouts while the track power is off. The Keyboard will then implicitly notice (or rather, not notice) that the turnout has not been switched.

It would be possible to extend the c6021light to generate a response on I2C. However, the c6021light can not reliably know the Stop/Go state of the system, causing the Keyboard to receive acknowledgements when nothing has been switched.

What is the goal of your setup? Are you planning to run without devices attached to CAN?

Regards
Damian

CuriousTimo, 2020-12-30:
Hi Damian,

Thanks for your reply. My goal would be to use the 6040 on a LocoNet standalone system. So much more lightweight than what you are developing I guess. Similar to the Uhlenbrock IB-Switch.

Since a standalone LocoNet system works independently from the DCC railsync controlling the trains it does not really bother with the state of the track power.

In combination with Rocrail, I would be able to dump all the 6040 states to Rocrail when it receives an OPC_GPON message.
Or I could let Rocrail send all its states to LocoNet.

Regards,
Timo

deltaphi, 2020-12-30:
Hi Timo,

at least in the latest master with the reworked command line interface, it would be relatively easy to add an option for the c6021light to (blindly?) generate responses on I2C.

What needs doing (roughly):
* Extend DataModel with a new parameter (and EEPROM index) to track whether responses on I2C should be generated.
* Extend RoutingTask::TaskMain, where the I2C Packet is processed, to generate responses based on this parameter.
* Extend ConsoleManager to add a parameter, e.g., "config [get|set] generateI2CTurnoutResponse [on|off]".
* Extend hal:StoreData and hal::LoadData to persist the new parameter.

Would you be interested in implementing this? I'd be happy to review your pull request. If you need more insight into one aspect or the other, feel free to ask.

To note: You may have to slow down the c6021light when sending the responses. In the initial version, I found that sending a reply after the I2C-mandated minimum delay of 4us was not received by the Keyboard. Delaying this time to about 9us from the end of reception of the request made the Keyboard happy. If there is a lot of forwarding going on before the reply is sent, the delay caused by the amount of code executed may be sufficient. A round-trip delay across CAN certainly has been sufficient.

CuriousTimo, 2020-12-30:
Thanks! I figured it out.

As a quick test, I have copied and pasted parts of your codebase to set up a one file Arduino sketch.

Reason for this that I can now test and develop it on my [LocoNet Nano PCBs](https://github.com/CuriousTimo/Arduino-ModelRail/tree/master/Arduino%20LocoNet-DCC%20Interface%20v2).

Over the last few weeks, I have been working on version 3 of my interface. This will have two expansion ports to break out the pins to expansion modules. I have expansion boards for 2x RFID, 16x LEDs (Signals), 16x Mass Detector Feedback on their way from China to be tested. If everything is ok I'll have to update the manual and push everything to GitHub.

Creating a small extension module with an onboard 8v power source to connect my LocoNet board to the Marklin i2c bus would be totally feasable.

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
V3 Nano LocoNet Board.

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
2x RFID Expansion Board.

Basically what I did is add a flag at the end of the receiveEvent routine.
When this is set to true it triggers the next loop to send the ack to the 6040 keyboard.

```
  if(TX == true) {
    delayMicroseconds(9);
    Wire.beginTransmission(i2cRxBuf.msgBytes[0] >> 1);
    Wire.write(kCentralAddr << 1);
    Wire.write(i2cRxBuf.msgBytes[1]);
    Wire.endTransmission();

    TX = false;
  }
```
This is working but I have to clean it up and use the routines in your library.

> at least in the latest master with the reworked command line interface, it would be relatively easy to add an option for the c6021light to (blindly?) generate responses on I2C.

I'm not sure if such an option would benefit your project tough? Since the use case is rather different.

deltaphi, 2020-12-31:
> > at least in the latest master with the reworked command line interface, it would be relatively easy to add an option for the c6021light to (blindly?) generate responses on I2C.
>
> I'm not sure if such an option would benefit your project tough? Since the use case is rather different.

The c6021light is not explicitly intended to be used exclusively with CAN as the Railroad-facing bus - it just so happens that you are the first person to have a different usecase. I would see such an option as a benefit.

Similarly - but more copmlex to solve - The initial version of this software could also be built on Arduino and be used with a CANdiy-Shield (No LocoNet at the time in the software). I have dropped the Arduino support since, as the software has grown in functionality and thus also size - it currently occupies roughly 7k RAM and 30k Flash on the Bluepill. However, if there is interest it would certainly be possible to either bring back a restricted Arduino port or to factor out helpful parts of c6021light as a separate library for use by other projects.

deltaphi, 2021-01-17:
Now implemented. See command line interface: `config set generateI2CTurnoutResponse`.

Closed 2021-01-17.

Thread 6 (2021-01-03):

I2C TX Message display swaps sender and receiver

deltaphi, 2021-01-03:
An I2C RX Message for Turnout 3 on the first Keyboard looks as follows (correct):

`I2C RX: [0x7f 0x20 0xd] - Keyboard: 0, Decoder: 2, (Turnout: 2, Direction: GREEN, Power: ON )`

When the c6021light sends a response (that is correctly interpreted by the correct Keyboard), it is incrrectly logged as:

`I2C TX: [0x20 0x7f 0xd] - Keyboard: 15, Decoder: 2, (Turnout: 242, Direction: GREEN, Power: ON )`

Spotted problem: The "Keyboard" value is taken from the sender, which in this case is not a Keyboard but the c6021light. The "Turnout" contains the same input as the "Keyboard" value and is thus similarly incorrect.

deltaphi, 2021-02-03:
With the fix for #9, the displayed values have changed, but are still wrong. This likely cannot be fixed without tracking the direction of the message (Inbound/Outbound).

Closed 2021-06-03.

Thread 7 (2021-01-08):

Serial Breakout RX/TX swapped

deltaphi, 2021-01-08:
As [reported by user markra in the stummiforum](https://www.stummiforum.de/viewtopic.php?p=2225311&sid=e822d6b1ebf340fec8044f3fbb1adf17#p2225311), on the first version of the PCB, the RX and TX lines for the serial header seem to be swapped.

Lines are not swapped when using a CH340.

GBert, 2021-01-08:
Fixed in PCB V1.3

Closed 2021-01-08.

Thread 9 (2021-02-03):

Keyboards with Address != 0 not handled correctly.

deltaphi, 2021-02-03:
When a Keyboard with address > 0 sends a request for turnout (e.g., Turnout 98), c6021light does not respect the keyboard address properly and instead sees a request for the same button on a Keyboard with Address 0 (e.g., Turnout 2 in this example). Responses are generated for the seen Keyboard not the actual Keyboard, locking the Keyboard in a loop.

deltaphi, 2021-02-03:
@glaserf I managed to recreate your bug report. Feel free to add anything you might have.

Closed 2021-02-03.

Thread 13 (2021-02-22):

Set function from CAN, Reset function from LocoNet, function is not reset.

deltaphi, 2021-02-22:
Furn on a Function (e.g., F1) on a CAN control device. A LocoNet device sees the function change. Turn off the Function from the LocoNet device. The function change is not seen by the CAN control device.

Turn the function on and off again on the LocoNet device. Now the CAN control device sees the change.

Closed 2021-02-22.

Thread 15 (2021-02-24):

Speed levels requested by LN devices always answered with one speed level lower

glaserf, 2021-02-24:
It seems speed levels requested from LN get answered with the level below. This leads to a "stiff" control behavior when increasing the speed of an engine; you basically have to beat the speed of the bus. When decelerating, slowing down is consequently accelerated by a factor of 2. Here is an example, RX are requested speed steps from LN:
```
LN RX:  a0 1 4 5a [OPC_LOCO_SPD] Slot: 1 Speed: 4
LN TX:  a0 1 3 20 [OPC_LOCO_SPD] Slot: 1 Speed: 3
LN RX:  a0 1 5 5b [OPC_LOCO_SPD] Slot: 1 Speed: 5
LN TX:  a0 1 4 20 [OPC_LOCO_SPD] Slot: 1 Speed: 4
LN RX:  a0 1 6 58 [OPC_LOCO_SPD] Slot: 1 Speed: 6
LN TX:  a0 1 5 20 [OPC_LOCO_SPD] Slot: 1 Speed: 5
LN RX:  a0 1 7 59 [OPC_LOCO_SPD] Slot: 1 Speed: 7
LN TX:  a0 1 6 20 [OPC_LOCO_SPD] Slot: 1 Speed: 6
LN RX:  a0 1 7 59 [OPC_LOCO_SPD] Slot: 1 Speed: 7
LN RX:  a0 1 8 56 [OPC_LOCO_SPD] Slot: 1 Speed: 8
LN TX:  a0 1 7 20 [OPC_LOCO_SPD] Slot: 1 Speed: 7
LN RX:  a0 1 8 56 [OPC_LOCO_SPD] Slot: 1 Speed: 8
LN RX:  a0 1 9 57 [OPC_LOCO_SPD] Slot: 1 Speed: 9
LN TX:  a0 1 8 20 [OPC_LOCO_SPD] Slot: 1 Speed: 8
```

As a consequence, an engine will lose one speed step per LN refresh cycle and will eventually stop:
```
LN RX:  a0 1 8 56 [OPC_LOCO_SPD] Slot: 1 Speed: 8
LN TX:  a0 1 7 20 [OPC_LOCO_SPD] Slot: 1 Speed: 7
- pause -
LN RX:  a0 1 7 59 [OPC_LOCO_SPD] Slot: 1 Speed: 7
LN TX:  a0 1 6 20 [OPC_LOCO_SPD] Slot: 1 Speed: 6
- pause -
LN RX:  a0 1 6 58 [OPC_LOCO_SPD] Slot: 1 Speed: 6
LN TX:  a0 1 5 20 [OPC_LOCO_SPD] Slot: 1 Speed: 5
- pause -
LN RX:  a0 1 5 5b [OPC_LOCO_SPD] Slot: 1 Speed: 5
LN TX:  a0 1 4 20 [OPC_LOCO_SPD] Slot: 1 Speed: 4
- pause -
LN RX:  a0 1 4 5a [OPC_LOCO_SPD] Slot: 1 Speed: 4
LN TX:  a0 1 3 20 [OPC_LOCO_SPD] Slot: 1 Speed: 3
- pause -
LN RX:  a0 1 3 5d [OPC_LOCO_SPD] Slot: 1 Speed: 3
LN TX:  a0 1 2 20 [OPC_LOCO_SPD] Slot: 1 Speed: 2
- pause -
LN RX:  a0 1 2 5c [OPC_LOCO_SPD] Slot: 1 Speed: 2
LN TX:  a0 1 1 20 [OPC_LOCO_SPD] Slot: 1 Speed: 1
- pause -
LN RX:  a0 1 1 5f [OPC_LOCO_SPD] Slot: 1 Speed: 1
LN TX:  a0 1 0 20 [OPC_LOCO_SPD] Slot: 1 Speed: 0
- pause -
LN RX:  a0 1 0 5e [OPC_LOCO_SPD] Slot: 1 Speed: 0
LN TX:  a0 1 0 20 [OPC_LOCO_SPD] Slot: 1 Speed: 0
```

deltaphi, 2021-02-27:
Can at least partially be reproduced with test cases added in 9e475f89cabccccb2c08a42db4349208e6de9056. There may be additional issues related to devices on the bus that are not reflected in unit testing.

Closed 2021-02-28.

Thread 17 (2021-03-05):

Wrong LED used

deltaphi, 2021-03-05:
Original report by @GBert

The Start/Stop state should be displayed using the off-board LED.

Closed 2021-03-05.

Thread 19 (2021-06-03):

CanEngine DB gets stuck on synchronous power-on

deltaphi, 2021-06-03:
When powering on the c6021light and an MS2 at the same time (say, through a switchable powerbar), the Engine DB Download on the c6021light gets stuck. A manual reset of the board is required. Starting the download through the serial interface does not work.

deltaphi, 2021-06-03:
Issue appears to be that the corresponding timer never expires.

Closed 2021-06-03.

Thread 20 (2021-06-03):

Status LED should differentiate between "Waiting for Download" and "Performing Download"

deltaphi, 2021-06-03:
When downloading the CanDB, the blink codes of the Status LED should indicate whether...
* The c6021light is currently requesting a download but not receiving data,
* The c6021light is receiving the engine list,
* The c6021light is receiving engines.

Currently, the LED changes only its frequency to indicate OK/ERROR/DOWNLOADING. In addition, the duty cycle could be adjusted to that, e.g., requesting is a short blip where receiving is a longer blip.

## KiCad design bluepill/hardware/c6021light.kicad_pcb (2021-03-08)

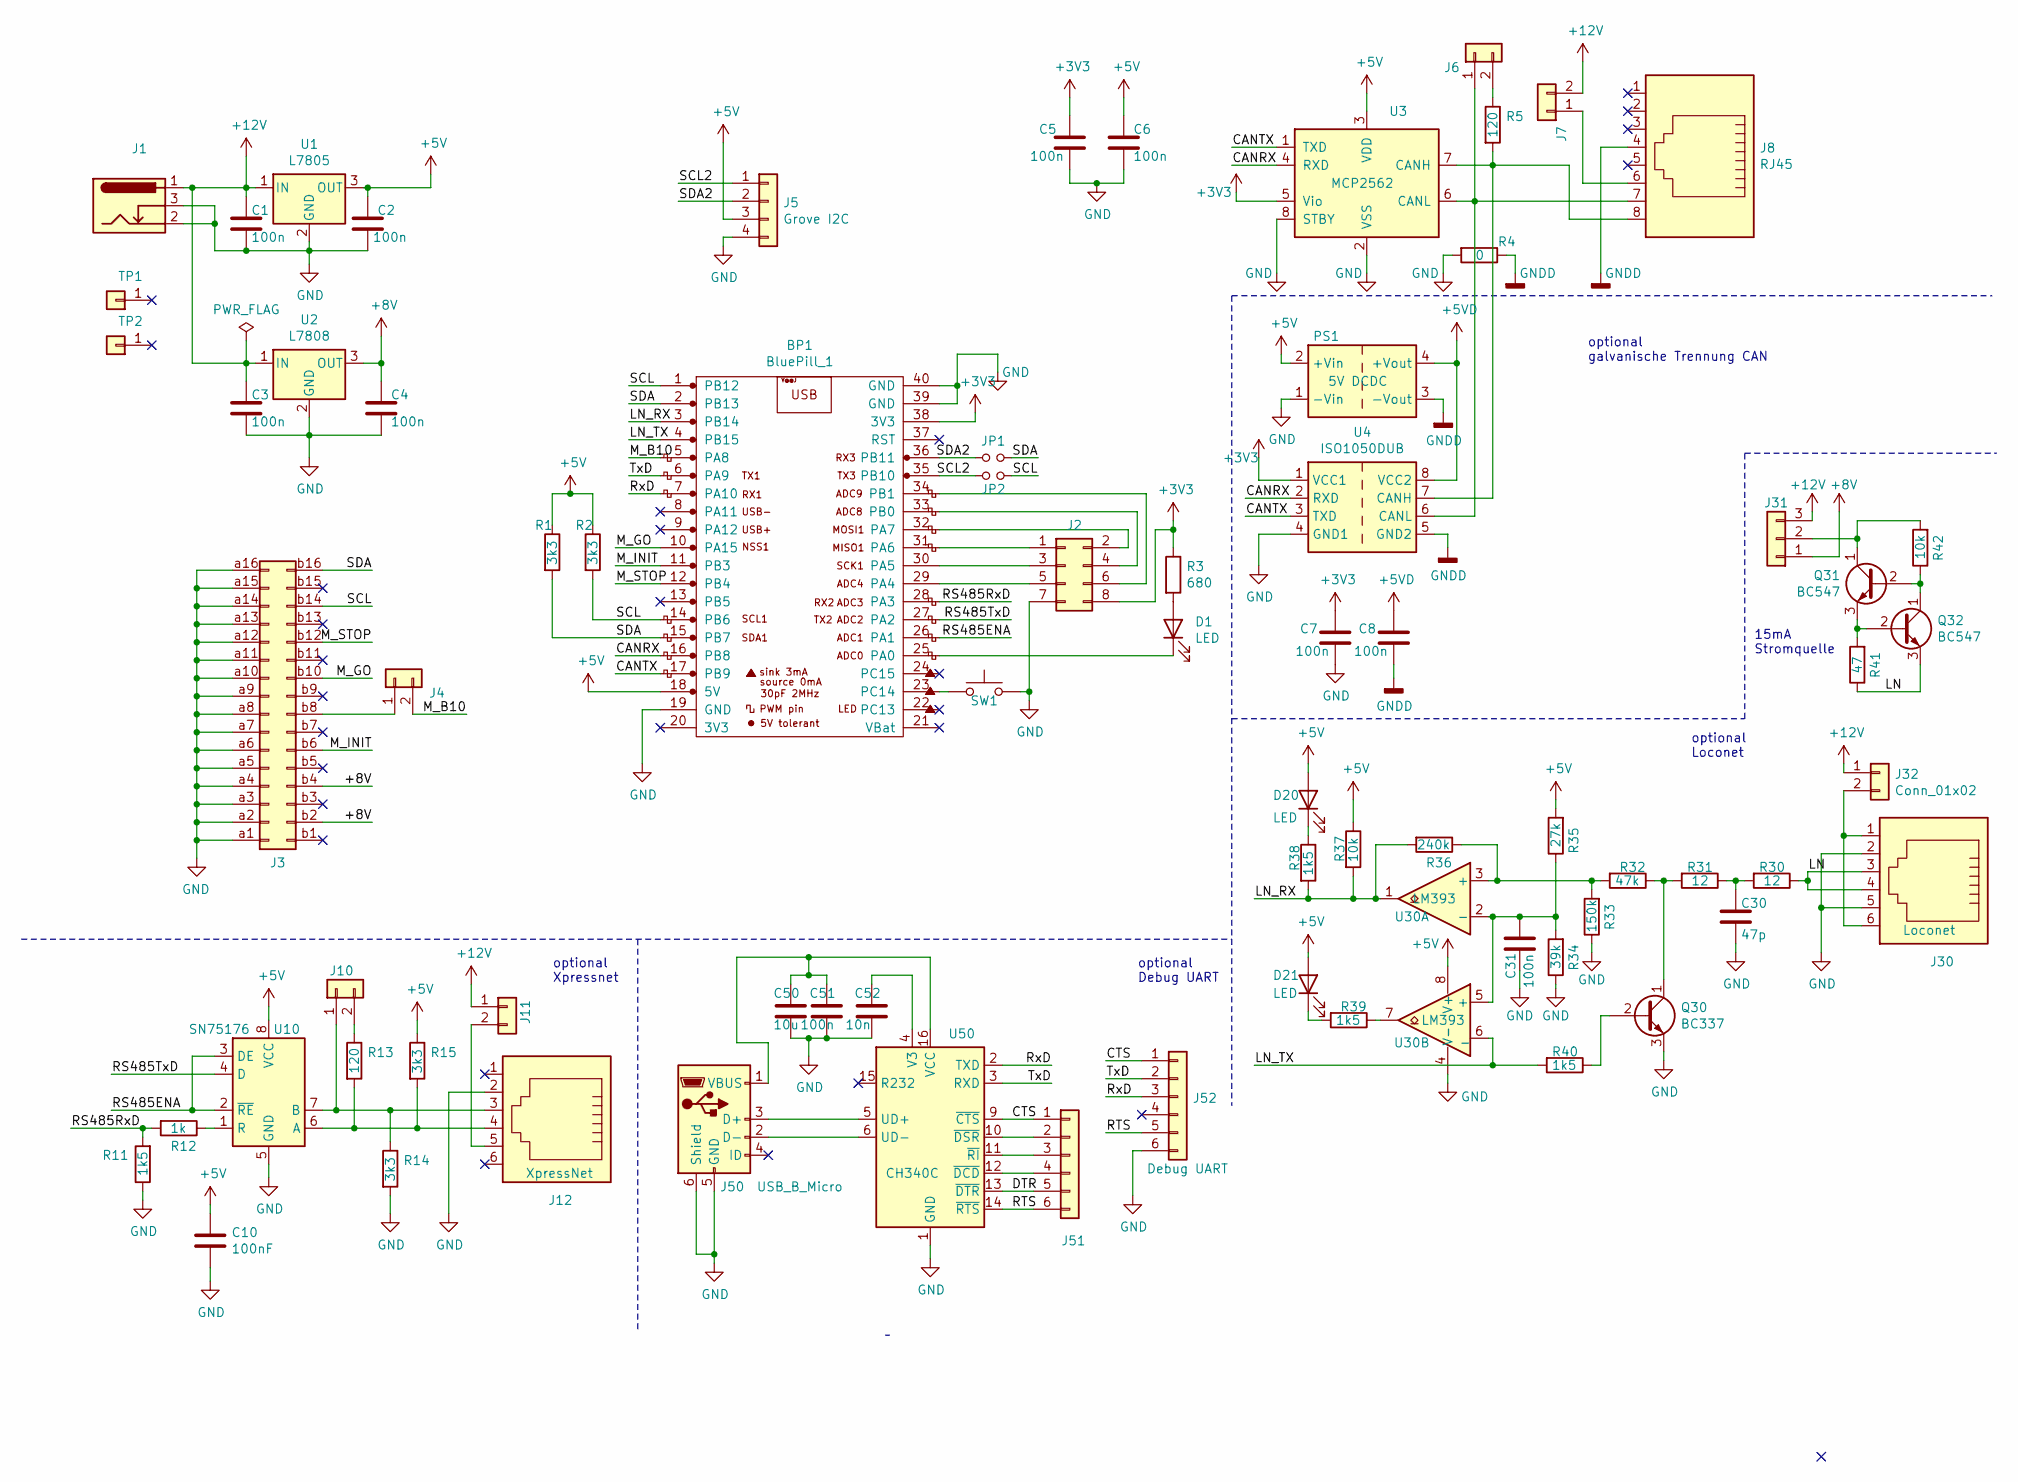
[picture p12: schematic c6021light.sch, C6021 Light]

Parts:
BP1: BluePill_1; YAAJ_BluePill
C1, C2, C3, C4, C5, C6, C7, C8, C31: 100n; C_Disc_D3.0mm_W1.6mm_P2.50mm
C10: 100nF; C_Disc_D3.0mm_W1.6mm_P2.50mm
C30: 47p; C_Rect_L7.0mm_W3.5mm_P2.50mm_P5.00mm
C50: 10u; C_0805_2012Metric
C51: 100n; C_0805_2012Metric
C52: 10n; C_0805_2012Metric
D1, D20, D21: LED; LED_D3.0mm
J1: Barrel_Jack_Switch; dc_socket
J2: Conn_02x04_Odd_Even; PinHeader_2x04_P2.54mm_Vertical
J3: Conn_02x16_Row_Letter_First; DIN41612_B2_2x16_Female_Vertical_THT
J4, J6, J7, J10, J11, J32: Conn_01x02; PinHeader_1x02_P2.54mm_Vertical_NB
J5: Grove I2C; b4b-ph-kl
J8: RJ45; mebp8
J12: XpressNet; RJ12_Amphenol_54601
J30: Loconet; RJ12_Amphenol_54601
J31: Conn_01x03; PinHeader_1x03_P2.54mm_Vertical
J50: USB_B_Micro; USB_Micro-B_Molex-105017-0001
J51: Conn_01x06; PinHeader_1x06_P1.27mm_Vertical
J52: Debug UART; PinHeader_1x06_P2.54mm_Vertical
JP1, JP2: Jumper_NO_Small; PinHeader_1x02_P2.54mm_Vertical
PS1: 5V DCDC; Converter_DCDC_Murata_MEE1SxxxxSC_THT
Q30: BC337; TO-92_Inline
Q31, Q32: BC547; TO-92_Inline
R1, R2: 3k3; R_Axial_DIN0207_L6.3mm_D2.5mm_P7.62mm_Horizontal
R3: 680; R_Axial_DIN0207_L6.3mm_D2.5mm_P7.62mm_Horizontal
R4: 0; R_AXIAL_0_WIRE
R5: 120; R_Axial_DIN0207_L6.3mm_D2.5mm_P7.62mm_Horizontal
R11, R38, R39, R40: 1k5; R_Axial_DIN0207_L6.3mm_D2.5mm_P7.62mm_Horizontal
R12: 1k; R_Axial_DIN0207_L6.3mm_D2.5mm_P7.62mm_Horizontal
R13: 120; RC03
R14, R15: 3k3; RC03
R30, R31: 12; R_Axial_DIN0207_L6.3mm_D2.5mm_P7.62mm_Horizontal
R32: 47k; R_Axial_DIN0207_L6.3mm_D2.5mm_P7.62mm_Horizontal
R33: 150k; R_Axial_DIN0207_L6.3mm_D2.5mm_P7.62mm_Horizontal
R34: 39k; R_Axial_DIN0207_L6.3mm_D2.5mm_P7.62mm_Horizontal
R35: 27k; R_Axial_DIN0207_L6.3mm_D2.5mm_P7.62mm_Horizontal
R36: 240k; R_Axial_DIN0207_L6.3mm_D2.5mm_P7.62mm_Horizontal
R37: 10k; R_Axial_DIN0207_L6.3mm_D2.5mm_P7.62mm_Horizontal
R41: 47; RC03
R42: 10k; RC03
SW1: SW_Push; PCB_PUSH
TP1, TP2: Conn_01x01; Test_Point_NA
U1: L7805; TO-220-3_Vertical
U2: L7808; TO-220-3_Vertical
U3: MCP2562; dil_8-300_socket
U4: ISO1050DUB; SOP-8_6.62x9.15mm_P2.54mm
U10: SN75176; dil_8-300_socket
U30: LM393; dil_8-300_socket
U50: CH340C; SOIC-16_3.9x9.9mm_P1.27mm

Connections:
+3V3: BP1.38 (3V3), C5.1, C7.1, J2.8, R3.1, U3.5 (Vio), U4.1 (VCC1)
+5V: BP1.18 (5V), C2.1, C6.1, C10.1, D20.2 (A), D21.2 (A), J5.3, PS1.2 (+Vin), R1.1, R2.1, R15.1, R35.2, R37.1, U1.3 (OUT), U3.3 (VDD), U10.8 (VCC), U30.8 (V+)
+5VD: C8.1, PS1.4 (+Vout), U4.8 (VCC2)
+8V: C4.1, J3.b2, J3.b4, J31.1, U2.3 (OUT)
+12V: C1.1, C3.1, J1.1, J7.2, J11.1, J31.3, J32.1, U1.1 (IN), U2.1 (IN)
/CANRX: BP1.16 (PB8), U3.4 (RXD), U4.2 (RXD)
/CANTX: BP1.17 (PB9), U3.1 (TXD), U4.3 (TXD)
/CTS: J51.1, J52.1, U50.9 (~CTS)
/DTR: J51.5, U50.13 (~DTR)
/LN: J30.3, J30.4, Q32.3 (E), R30.1, R41.1
/LN_RX: BP1.3 (PB14), R36.2, R37.2, R38.2, U30.1
/LN_TX: BP1.4 (PB15), R40.2, U30.6 (_)
/M_B10: BP1.5 (PA8), J4.2
/M_GO: BP1.10 (PA15), J3.b10
/M_INIT: BP1.11 (PB3), J3.b6
/M_STOP: BP1.12 (PB4), J3.b12
/RS485ENA: BP1.26 (PA1), U10.2 (~RE), U10.3 (DE)
/RS485RxD: BP1.28 (PA3), R11.2, R12.2
/RS485TxD: BP1.27 (PA2), U10.4 (D)
/RTS: J51.6, J52.5, U50.14 (~RTS)
/RxD: BP1.7 (PA10), J52.3, U50.2 (TXD)
/SCL: BP1.1 (PB12), BP1.14 (PB6), J3.b14, JP2.2, R2.2
/SCL2: BP1.35 (PB10), J5.1, JP2.1
/SDA: BP1.2 (PB13), BP1.15 (PB7), J3.b16, JP1.2, R1.2
/SDA2: BP1.36 (PB11), J5.2, JP1.1
/TxD: BP1.6 (PA9), J52.2, U50.3 (RXD)
GND: BP1.19 (GND), BP1.39 (GND), BP1.40 (GND), C1.2, C2.2, C3.2, C4.2, C5.2, C6.2, C7.2, C10.2, C30.2, C31.2, C50.2, C51.2, C52.2, J1.2, J1.3, J2.7, J3.a1, J3.a2, J3.a3, J3.a4, J3.a5, J3.a6, J3.a7, J3.a8, J3.a9, J3.a10, J3.a11, J3.a12, J3.a13, J3.a14, J3.a15, J3.a16, J5.4, J12.2, J30.2, J30.5, J50.5 (GND), J50.6 (Shield), J52.6, PS1.1 (-Vin), Q30.3 (E), R4.2, R11.1, R14.2, R33.1, R34.1, SW1.2, U1.2 (GND), U2.2 (GND), U3.2 (VSS), U3.8 (STBY), U4.4 (GND1), U10.5 (GND), U30.4 (V-), U50.1 (GND)
GNDD: C8.2, J8.4, PS1.3 (-Vout), R4.1, U4.5 (GND2)
unnamed: BP1.23 (PC14), SW1.1
unnamed: BP1.25 (PA0), D1.1 (K)
unnamed: BP1.29 (PA4), J2.5
unnamed: BP1.30 (PA5), J2.3
unnamed: BP1.31 (PA6), J2.1
unnamed: BP1.32 (PA7), J2.2
unnamed: BP1.33 (PB0), J2.4
unnamed: BP1.34 (PB1), J2.6
unnamed: C30.1, R30.2, R31.1
unnamed: C31.1, R34.2, R35.1, U30.2 (-), U30.5 (+)
unnamed: C50.1, C51.1, J50.1 (VBUS), U50.16 (VCC)
unnamed: C52.1, U50.4 (V3)
unnamed: D1.2 (A), R3.2
unnamed: D20.1 (K), R38.1
unnamed: D21.1 (K), R39.2
unnamed: J3.b8, J4.1
unnamed: J6.1, J8.7, U3.6 (CANL), U4.6 (CANL)
unnamed: J6.2, R5.1
unnamed: J7.1, J8.6
unnamed: J8.8, R5.2, U3.7 (CANH), U4.7 (CANH)
unnamed: J10.1, J12.3, R14.1, U10.7 (B)
unnamed: J10.2, R13.1
unnamed: J11.2, J12.5
unnamed: J12.4, R13.2, R15.2, U10.6 (A)
unnamed: J30.1, J30.6, J32.2
unnamed: J31.2, Q31.1 (C), R42.2
unnamed: J50.2 (D-), U50.6 (UD-)
unnamed: J50.3 (D+), U50.5 (UD+)
unnamed: J51.2, U50.10 (~DSR)
unnamed: J51.3, U50.11 (~RI)
unnamed: J51.4, U50.12 (~DCD)
unnamed: Q30.1 (C), R31.2, R32.1
unnamed: Q30.2 (B), R40.1
unnamed: Q31.2 (B), Q32.1 (C), R42.1
unnamed: Q31.3 (E), Q32.2 (B), R41.2
unnamed: R12.1, U10.1 (R)
unnamed: R32.2, R33.2, R36.1, U30.3 (+)
unnamed: R39.1, U30.7

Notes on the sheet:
optional Xpressnet
optional Debug UART
optional Loconet
optional galvanische Trennung CAN
15mA Stromquelle

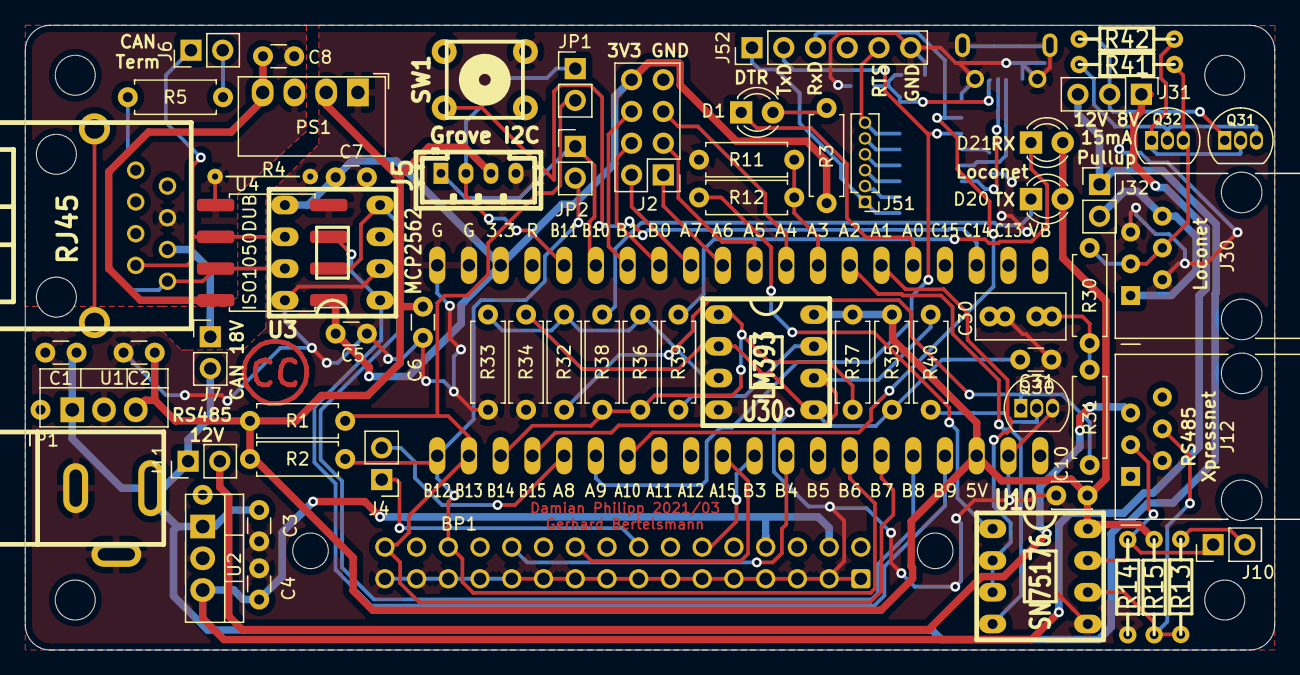
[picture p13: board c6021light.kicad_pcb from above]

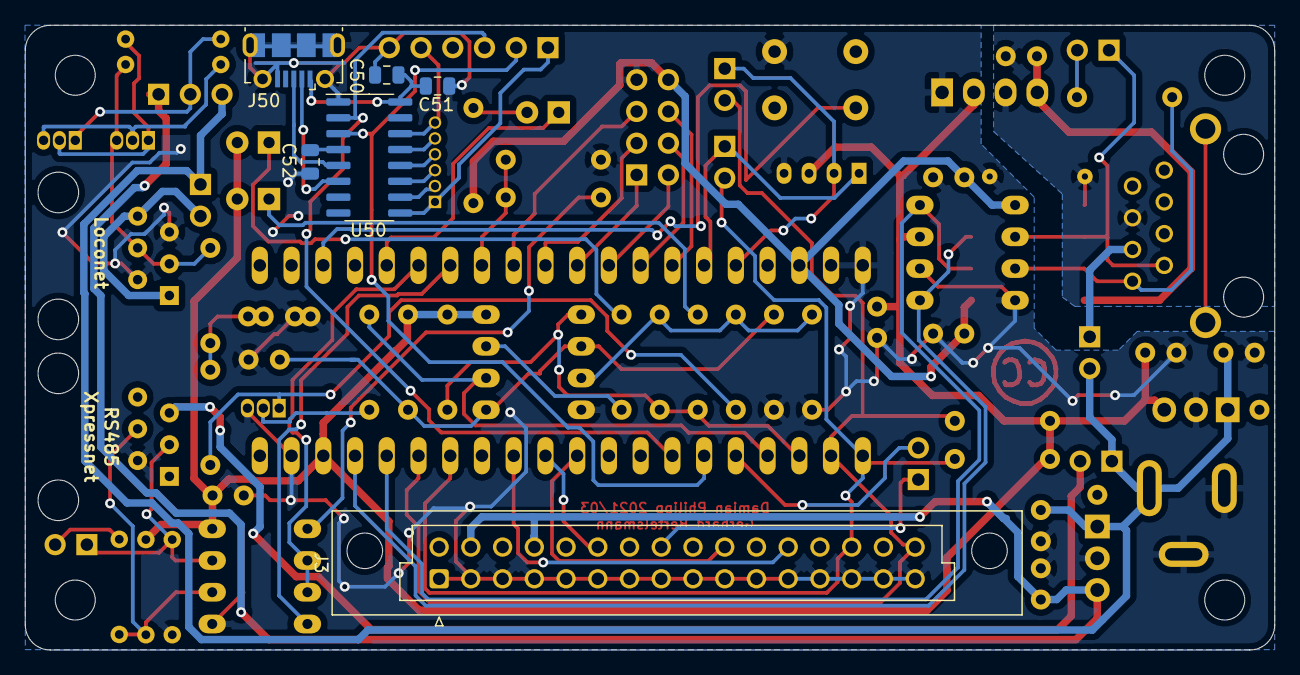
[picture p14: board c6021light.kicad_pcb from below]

Board: 2 copper layers, 100.0 x 50.0 mm, 74 parts (6 on the bottom side), 66 nets.

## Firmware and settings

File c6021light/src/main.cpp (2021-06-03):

// KeyboardDemoSketch
// Demonstrates the i2c communication with a Marklin Keyboard.
// Sends responses to a Keyboard and dumps the received command to the serial console.

// Note that this sketch is not robust against other messages. Recieving engine control messages
// Will likely require a reboot of the uC.

extern "C" {
#include <stdio.h>
#include <string.h>
}

#include <hal/LibOpencm3Hal.h>
#include "hal/stm32I2C.h"
#include "hal/stm32can.h"
#include "hal/stm32eepromEmulation.h"
#include "hal/stm32usart.h"

#include <FreeRTOS.h>
#include "OsTask.h"
#include "OsTimer.h"
#include "timers.h"

#include "RR32Can/RR32Can.h"
#include "RR32Can/StlAdapter.h"
#include "RR32Can_config.h"

using Hal_t = hal::LibOpencm3Hal;

extern "C" {
#include "microrl.h"
}

#include "ConsoleManager.h"
#include "DataModel.h"
#include "StartStopIndicator.h"
#include "StatusIndicator.h"
#include "tasks/ConsoleTask/ConsoleTask.h"
#include "tasks/RoutingTask/RoutingTask.h"

// ******** Variables and Constans********
Hal_t halImpl;

DataModel dataModel;
freertossupport::StaticOsTask<tasks::RoutingTask::RoutingTask,
                              tasks::RoutingTask::RoutingTask::kStackSize>
    routingTask;
freertossupport::StaticOsTask<tasks::ConsoleTask::ConsoleTask,
                              tasks::ConsoleTask::ConsoleTask::kStackSize>
    consoleTask;

freertossupport::StaticOsTimer stopGoTimer;
freertossupport::StaticOsTimer canEngineDbRequestTimer;
freertossupport::StaticOsTimer statusLedTimer;
freertossupport::StaticOsTimer stopGoLedTimer;

hal::CanTxCbk canTxCbk;

LocoNetTx lnTx;

StatusIndicator statusIndicator;
StartStopIndicator startStopIndicator;

// Dummy variable that allows the toolchain to compile static variables that have destructors.
void* __dso_handle;

// ******** Code ********
extern "C" {
void vApplicationGetIdleTaskMemory(StaticTask_t** ppxIdleTaskTCBBuffer,
                                   StackType_t** ppxIdleTaskStackBuffer,
                                   uint32_t* pulIdleTaskStackSize) {
  static StackType_t idleTaskStack[configMINIMAL_STACK_SIZE];
  static StaticTask_t idleTaskTcb;
  *ppxIdleTaskTCBBuffer = &idleTaskTcb;
  *ppxIdleTaskStackBuffer = idleTaskStack;
  *pulIdleTaskStackSize = configMINIMAL_STACK_SIZE;
}

void vApplicationGetTimerTaskMemory(StaticTask_t** ppxTimerTaskTCBBuffer,
                                    StackType_t** ppxTimerTaskStackBuffer,
                                    uint32_t* pulTimerTaskStackSize) {
  static StackType_t timerTaskStack[configTIMER_TASK_STACK_DEPTH];
  static StaticTask_t timerTaskTcb;
  *ppxTimerTaskTCBBuffer = &timerTaskTcb;
  *ppxTimerTaskStackBuffer = timerTaskStack;
  *pulTimerTaskStackSize = configTIMER_TASK_STACK_DEPTH;
}

}  // extern "C"

namespace {
void setup() {
  // Setup I2C & CAN
  halImpl.begin();
  statusIndicator.begin(statusLedTimer, halImpl);
  startStopIndicator.begin(stopGoLedTimer, halImpl);
  hal::beginSerial();
  hal::beginEE();
  hal::beginI2C(dataModel.kMyAddr, routingTask);
  hal::beginCan(routingTask);

  // Setup Serial
  printf("Connect6021Light Initializing...\n");

  // Load Configuration
  printf("Reading Configuration.\n");
  dataModel = hal::LoadConfig();
  routingTask.begin(dataModel, lnTx, stopGoTimer, canEngineDbRequestTimer, statusIndicator);

  // Tie callbacks together
  printf("Setting up callbacks.\n");

  RR32Can::Station::CallbackStruct callbacks;
  callbacks.tx = &canTxCbk;
  callbacks.system = &startStopIndicator;
  callbacks.engine = &routingTask.getCANEngineDB();
  RR32Can::RR32Can.begin(RR32CanUUID, callbacks);

  consoleTask.setup(lnTx);
  printf("Ready!\n");
  ConsoleManager::begin(&dataModel);

  // Start anything timer-related
  routingTask.stopGoStateM_.startRequesting();
  routingTask.canEngineDBStateM_.startRequesting();
}

void setupOsResources() {
  stopGoTimer.Create("StopGo", 1000, true, &routingTask.stopGoStateM_);
  canEngineDbRequestTimer.Create("CanDb", 1000, true, &routingTask.canEngineDBStateM_);
  statusLedTimer.Create("StatusLED", 1000, true, &statusIndicator);
  stopGoLedTimer.Create("StartStop", 1000, true, &startStopIndicator);
}

void setupOsTasks() {
  routingTask.Create("RoutingTask", configMAX_PRIORITIES - 1);
  consoleTask.Create("ConsoleTask",
                     0);  // Lowest prio as this task will always run.
}
}  // namespace

// Main function for non-arduino
int main(void) {
  setupOsResources();
  setupOsTasks();

  setup();

  vTaskStartScheduler();

  while (1) {
    ;
  }
  return 0;
}

extern "C" void notifyLnByteReceived() { routingTask.notifyFromISRWithWake(); }

namespace ConsoleManager {

int run_ln_slot_server_dump(int argc, const char* const* argv, int argcMatched) {
  static constexpr const char* appName{"LnSlotServerDump"};
  if (!checkNumArgs(argc - argcMatched, 0, 0, appName)) {
    display_help(argc, argv);
    return -2;
  }

  routingTask.getLnSlotServer().dump();

  return 0;
}

int run_ln_slot_server_dispatch(int argc, const char* const* argv, int argcMatched) {
  static constexpr const char* appName{"LnSlotServerDispatch"};

  if (!checkNumArgs(argc - argcMatched, 1, 1, appName)) {
    display_help(argc, argv);
    return -2;
  }

  const int dispatchAddrInt = atoi(argv[argcMatched]);

  using LocoAddr_t = tasks::RoutingTask::LocoNetSlotServer::LocoAddr_t;
  const LocoAddr_t dispatchAddress = RR32Can::MachineLocomotiveAddress(dispatchAddrInt);
  auto& slotServer = routingTask.getLnSlotServer();
  slotServer.markAddressForDispatch(dispatchAddress);
  return 0;
}

int run_app_download_enginedb_can(int, const char* const*, int) {
  statusIndicator.setCanDbDownload();
  routingTask.getCANEngineDB().fetchEngineDB();
  return 0;
}

int run_app_dump_enginedb_can(int, const char* const*, int) {
  routingTask.getCANEngineDB().dump();
  return 0;
}

}  // namespace ConsoleManager

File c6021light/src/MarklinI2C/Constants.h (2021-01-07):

#ifndef __MARKLINI2C__CONSTANTS_H__
#define __MARKLINI2C__CONSTANTS_H__

#include <cstdint>

namespace MarklinI2C {
/// Maximum length of a message in bytes.
constexpr const uint8_t kMessageMaxBytes = 4;
constexpr const uint8_t kSenderByte = 0;
constexpr const uint8_t kDestinationByte = 1;

constexpr const uint8_t kAccessoryMessageLength = 3;
constexpr const uint8_t kLocoMessageLength = 3;
constexpr const uint8_t kFunctionMessageLength = kLocoMessageLength;

/// I2C Address of the central.
constexpr const uint8_t kCentralAddr = 0x7F;

/// Bitmask containing sender bits.
constexpr const uint8_t kSenderAddrMask = 0b00011110;

/// Bitmask containing the message type bits.
constexpr const uint8_t kMsgTypeMask = 0b01100000;
constexpr const uint8_t kMsgTypeLoco = 0b00000000;
constexpr const uint8_t kMsgTypeAccessory = 0b00100000;
constexpr const uint8_t kMsgTypeFunction = 0b01000000;

/// Accessory Data: The direction bit.
constexpr const uint8_t kDataDirMask = 0x01;
constexpr const uint8_t kDataDirRed = 0x00;
constexpr const uint8_t kDataDirGreen = 0x01;
constexpr const uint8_t kDataPowerConsistentMask = 0xF0;

/// Accessory Data: The power on/off bit.
constexpr const uint8_t kDataPowerMask = 0b00001000;

/// Accessory Data: The turnout address lower bits.
constexpr const uint8_t kDataLowerAddrMask = 0b00000110;
constexpr const uint8_t kDataUpperAddrMask = 0b00110000;

}  // namespace MarklinI2C

#endif  // __MARKLINI2C__CONSTANTS_H__

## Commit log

2020-05-23 Added Demo-Sketch to receive and send keyboard messages on I2C.
2020-05-23 Add an MCP2515 driver. Reception not fully working.
2020-05-23 Switched to less efficient CAN library that supports extended frames.
2020-05-23 Rudimentary transmission from I2C to CAN.
    Known Issues:
    * Power Off does not work correctly.
    * Power State of CAN side is completely ignored.
    * No feedback from CAN to i2c.
    [main.cpp]
2020-05-24 Enalbe transmission of accessory commands from CAN to I2C.
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2020-05-25 add some basic files for STM32 Blue Pill
2020-05-25 Add initial HAL abstraction for Arduino and libopencm3
2020-05-28 Compiling (but untested!) code for partial i2c setup.
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2020-05-30 More work on enabling I2C
2020-05-31 Improve I2C on Bluepill
2020-05-31 Fixup of latest I2C improvement
    [LibOpencm3Hal.cpp]
2020-06-02 Made I2C Transmissions work.
2020-06-05 working on PCB
    [c6021light.kicad_pcb, c6021light.sch]
2020-06-06 fix PB2 (no 5V) and add push button
    [c6021light.sch]
2020-06-06 Hotfix for Timing Issue on I2C.
    [main.cpp]
2020-06-06 Better fix for timing issues
    [main.cpp]
2020-06-08 close to first release
    [c6021light-B_Cu.gbl, c6021light-B_Mask.gbs, c6021light-B_SilkS.gbo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]
2020-06-08 closer to V1.0
    [c6021light-B_Cu.gbl, c6021light-B_Mask.gbs, c6021light-B_SilkS.gbo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]
2020-06-09 more fixes
    [c6021light-B_Cu.gbl, c6021light-B_Mask.gbs, c6021light-B_SilkS.gbo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]
2020-06-09 fix DIN socket
    [c6021light-B_Cu.gbl, c6021light-B_Mask.gbs, c6021light-B_SilkS.gbo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]
2020-06-09 fix name
    [c6021light-B_Cu.gbl, c6021light-B_Mask.gbs, c6021light-B_SilkS.gbo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]
2020-06-09 move&add some references - looks better
    [c6021light-B_Cu.gbl, c6021light-B_Mask.gbs, c6021light-B_SilkS.gbo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]
2020-06-09 optimize routing a little bit
    [c6021light-B_Cu.gbl, c6021light-B_Mask.gbs, c6021light-B_SilkS.gbo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]
2020-06-09 add 12V power supply option for Loconet / chnage 1x2 pinh header footprint
    [c6021light-B_Cu.gbl, c6021light-B_Mask.gbs, c6021light-B_SilkS.gbo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]
2020-06-09 just to be sure everything is actual
    [c6021light-B_Cu.gbl, c6021light-B_Mask.gbs, c6021light-B_SilkS.gbo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]
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2020-06-10 add actual schematic pdf
2020-06-10 Added .gitignore for KiCad
2020-06-11 Added Arduino-like timing APIs
2020-06-11 Enable GPIO for the LED on PC13.
2020-06-11 Forward only response packets to I2C.
2020-06-11 Converted interrupt to flag message instead of receiving it
2020-06-11 Switch CAN to full polling mode
2020-06-13 Removed automatic sending of I2C responses.
    Fixes #1.
    [LibOpencm3Hal.cpp, main.cpp]
2020-06-13 Added STOP status display using the on-board LEDs.
2020-06-28 Make Accessory Rail Protocol Compile-Time Configurable.
2020-08-08 Better inclusion of microrl
    * CRLF Handling using Putty is buggy.
    [LibOpencm3Hal.cpp, main.cpp]
2020-08-08 First batch of fixes for PlatformIOs libopencm3 update
    [LibOpencm3Hal.cpp]
2020-08-08 Revert "First batch of fixes for PlatformIOs libopencm3 update"
    This reverts commit e16df5f3cdad017bb65763c7d80a15ebf0c1aa4a.
    [LibOpencm3Hal.cpp]
2020-08-10 Completed updates for environment update
    * Added Linker Flag for stdio.h not provided by PIO.
    * Fixed CAN Mask being set incorrectly.
    [LibOpencm3Hal.cpp]
2020-08-10 Arduino fixes.
2020-08-16 Dropped Support for Arduino (Uno).
    With the addition of microrl, the resulting code did not fit into an Atmega328 anymore.
    [ConsoleManager.cpp, Constants.h, LibOpencm3Hal.cpp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]
2020-08-17 new PCB version 1.1. aka 2020/08 with some small fixes
    [c6021light-B_Cu.gbl, c6021light-B_Mask.gbs, c6021light-B_SilkS.gbo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]
2020-11-13 Switch to glue code that also works in debugger
2020-11-14 Restructuring to move towards FreeRTOS.
    * I2C RX/TX split out to a mostly C-Style module.
    * RoutingTask split out.
2020-11-14 Switched to FreeRTOS static memory allocation.
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2020-11-21 Added a fairly crude I2C RX Queue
2020-11-22 Convert I2C Transmission to Queueing.
2020-11-29 Make RoutingTask Event-Driven.
    * CAN ISR and I2C ISR now send a Direct-to-Task notification to unblock the RoutingTask.
    * Extract console handling to separate (polling) Task.
2020-11-30 Initialize GPIO pin for off-board LED.
2020-11-30 Add POC ISR for LocoNet RX Pin.
2020-12-01 Test implementation for SW-UART with approximately correct timing.
    [LibOpencm3Hal.cpp]
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2020-12-06 Added dependency to ongoing STM32 Port of LocoNet
2020-12-11 Fix generation of Power-Off Responses on I2C
    [RoutingTask.cpp]
2020-12-11 Add I2C RX Watchdog timer.
    Cancels an RX transmission when a full message was received, but no STOP condition was detected. This works around an issue with the Memory with black Dip switches.
    [main.cpp]
2020-12-11 Better fix for I2C responses.
    [RoutingTask.cpp]
2020-12-12 Added I2C Error ISR
2020-12-12 Remove now unneeded I2C Watchdog Timer.
2020-12-15 Started rework on RoutingTask structure.
    [RoutingTask.cpp]
2020-12-16 new PCB version
    [c6021light-B_Cu.gbl, c6021light-B_Mask.gbs, c6021light-B_SilkS.gbo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]
2020-12-16 change version on PCB
    [c6021light-B_Cu.gbl, c6021light-B_Mask.gbs, c6021light-B_SilkS.gbo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]
2020-12-16 save PCB forgotten
    [c6021light.kicad_pcb]
2020-12-17 Attempt to make USART DMA working. Not working, yet.
    [LibOpencm3Hal.cpp]
2020-12-18 Initial workings of DMA, breaks after a short while.
    [LibOpencm3Hal.cpp]
2020-12-19 Make DMA work fully
2020-12-20 Fix _write return value.
    [stm32usart.cpp]
2020-12-21 Add design documentation.
    Fix code inconsistency.
    [RoutingTask.cpp, stm32can.cpp]
2020-12-23 Fix Serial Output in high-volume situations
    [stm32usart.cpp]
2020-12-27 Switch to refactored AtomicRingBuffer
2020-12-27 Fix bugs in CLI completion
    [ConsoleManager.cpp]
2020-12-28 Transmit Sensor messages from LocoNet
2020-12-29 Plug accidentall fallthrough hole.
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2020-12-29 More extensive LocoNet printing
2020-12-29 Added initially empty LocoNet SlotServer
2020-12-30 Updated call handling but broke help display
    [ConsoleManager.cpp]
2020-12-30 Fixed unused paramter warnings
    [ConsoleManager.cpp]
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2020-12-31 Add tracking of state for a remote slot server
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2021-01-02 Added requesting of slot data in non-disabled mode
2021-01-02 Remove filtering of Power Responses from CAN
    Now possible as forwarding to LocoNet no longer triggers an echo.
    [RoutingTask.cpp]
2021-01-02 Fix a potential merge problem
    [stm32usart.cpp]
2021-01-03 Add anonymous namespace to save a couple of bytes.
2021-01-03 CanDB can now track velocity changes of Engines on CAN
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2021-01-04 Forward engine messages only if the slotserver is active
2021-01-05 Fully hide CAN and I2C behind method calls
2021-01-05 Converted I2C interface to use Message type only
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2021-01-06 use RAII for RX Pointers handed out by I2C and CAN
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2021-01-08 swap TxD and RxD on J52 header for standard USB2Serial moduls
    [c6021light-B_Cu.gbl, c6021light-B_Mask.gbs, c6021light-B_SilkS.gbo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]
2021-01-08 fix silkscreen
    [c6021light-B_Cu.gbl, c6021light-B_Mask.gbs, c6021light-B_SilkS.gbo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]
2021-01-09 change PCB marking to 2021/01
    [c6021light-B_Cu.gbl, c6021light-B_Mask.gbs, c6021light-B_SilkS.gbo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]
2021-01-17 Enable runtime-configuration of I2C responses
    Fixes #5.
    [ConsoleManager.cpp, DataModel.h]
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2021-02-03 I2C RX no longer overwrites the destination_
    Now correctly populates the source.
    Fixes #9.
2021-02-06 Add asynchronous TX for LocoNet.
    Current Queue depth: 1
2021-02-20 Added Tests and initial fixes for SlotServer
    [SlotServer.cpp]
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2021-02-21 Fix initial slot state
    FREDI will only pick up inUse slots.
    [SlotServer.cpp]
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2021-02-21 Prevent repeated dispatch of same address
    [SlotServer.cpp]
2021-02-21 Send Dummy switch reports when Slot Server is active.
    Lets users use the Turnout mode of a Daisy.
2021-02-22 SlotServer tracks state change from forwarded messages.
    Fixes #13
2021-02-27 Fix GCC9 compile error
    [EngineRouting.cpp]
2021-02-28 Add support for F20..28
    Fixes #14.
    [EngineRouting.cpp]
2021-02-28 Fix rounding for Speed/Velocity conversion.
    Fixes #15.
    [EngineRouting.cpp]
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2021-03-05 Swap status and StartStop LEDs.
    Fixes #17.
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2021-04-25 Added workarounds for Eclipse
    [CanEngineDBRequest.cpp]
2021-04-25 Fix CanDB Download not workiing.
    StateMachine would request a download while a download was already in
    progress, thus upsetting the parser side.
    [CanEngineDBRequest.cpp]
2021-04-25 Signal CAN DB Download using On-Board LED.
    Relates to #18.
2021-05-30 Signal when STOP/GO state of the system is unknown.
    Flashes the off-board LED as long as the Start/Stop state of the system is unknown.
    Closes #18.
2021-05-31 First take at fixing line endings.
    May do incomplete writes.
    Relates to #16.
    [ConsoleManager.cpp, stm32usart.cpp]
2021-05-31 Improved serial output.
    Fixes #16.
    [ConsoleManager.cpp, stm32usart.cpp]
2021-06-03 Fix display of decoded keyboard address for I2C
    * Removed display option for Arduino Serial
    * Keyboard address and turnour address are now decoded according to the stated direction of the message.
    Fixes #6.
    [I2CForwarder.cpp, RoutingTask.cpp]
2021-06-03 Increase timer command queue length.
    Relates to #19.
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2024-07-06 Fix output name of the DCC protocol
    [ConsoleManager.cpp]
2024-12-27 Update for newer libopencm3
    * Remove call to i2c_reset()
    * Use recommended magic number instead of I2C frequency define
2024-12-27 Fix turnout porotocol matching (#28)
    The original implementation always matched for MM1. The update from #25 changed this to match for a configured value. However, When using MM2 as the rail protocol, accessory packets are still MM1. This code still matches the configured value, but accepts MM1 and MM2 as being equal.
    [I2CForwarder.cpp]
2025-01-10 Add STL files and readme for the Housing (#32)
    [c6021lightHousing - Top.stl]
2026-10-11 Update for GitHub Action compatibility (#36)
    * Switch to newer VisualStudio for GitHub Action compatibility
    * Updaet Googletest revision
    * Bump GoogleTest CMake version requirements
2026-10-14 Pin OpenOCD version (#48)
    * Pinned old openocd Version to work around hla_swd upload protocol problem
    * Update Renovate for pinned OpenOCD package
2026-10-14 Fix serial output deadlock (#35)
    * Explicitly release DMA when there is nothing left to send
2026-10-15 Update dependency platformio/platform-ststm32 to v20 (#52)
    * Update dependency platformio/platform-ststm32 to v20
    * Un-Pin OpenOCD
    ---------
2026-10-27 Add version command (#30)
    * Add a version command with a hardcoded version string
    * Add script to generate git revision
    * Print version on startup
